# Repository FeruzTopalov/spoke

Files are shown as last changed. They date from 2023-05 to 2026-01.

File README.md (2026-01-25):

# **SPOKE*** - _Stay close!_ 
_*Like a spoke in a wheel_

<p align="center">
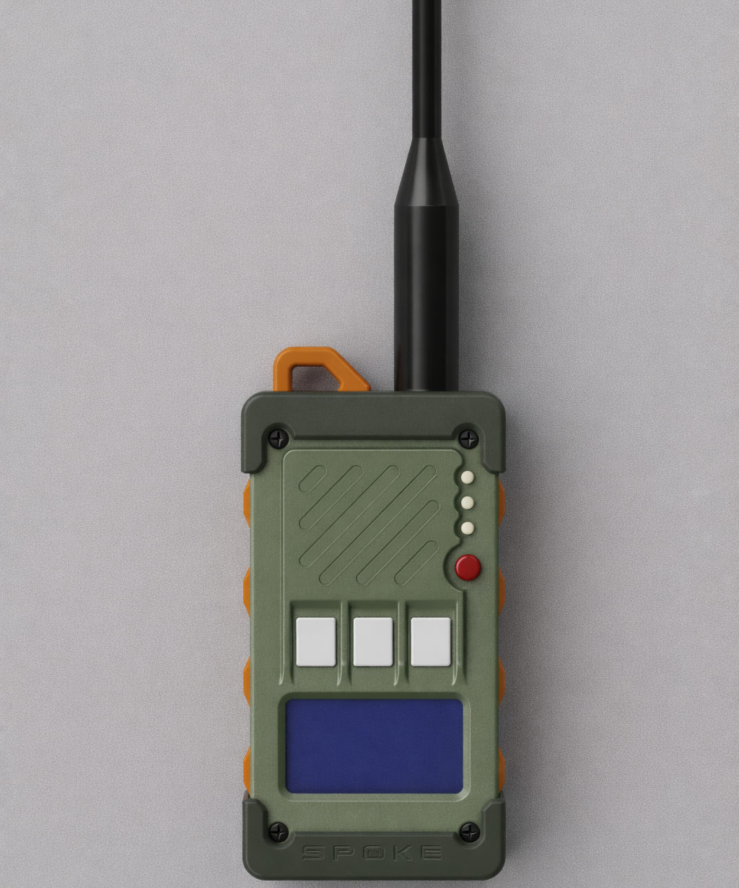
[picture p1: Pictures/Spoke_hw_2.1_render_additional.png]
Spoke Device Render
  
</p>

<p align="center">
🔓 Open-source<br>
🛠️ Open-hardware<br>
🛰️ GPS-based<br>
📡 LoRa-enabled<br>
🔋 Off-grid<br>
✨ Feature-rich<br>
🧭 Local Relative Navigation System<br>
<br>
or<br>
<br>
📍 just a LoRa GPS tracker for group 😉<br>
</p>

<p align="center">
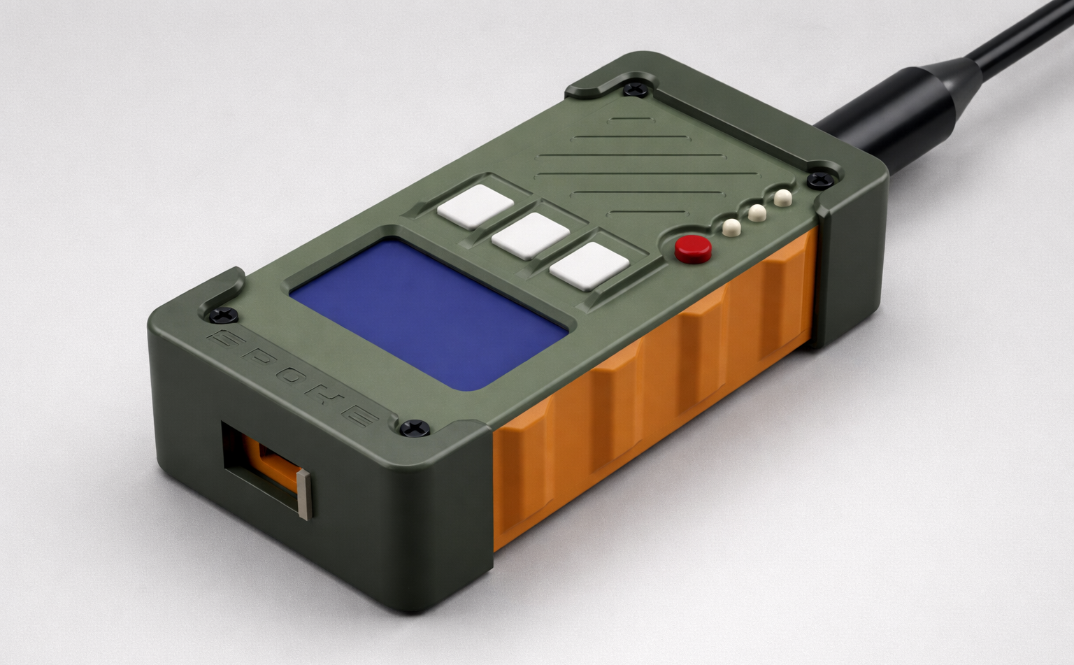
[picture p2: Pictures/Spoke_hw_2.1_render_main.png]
Spoke Device Render
  
</p>

---

## 📋 Table of Contents

- [About](#about)
- [Use Cases](#use-cases)
- [Key Features](#key-features)
- [Hardware](#hardware)
- [Technology & How It Works](#technology--how-it-works)
- [Navigation Algorithms](#navigation-algorithms)
- [Getting Started](#getting-started)
- [Configuration](#configuration)
- [Frequency Bands](#frequency-bands)
- [Community](#community)
- [Contributing](#contributing)
- [Support the Project](#support-the-project)

---

## About

**Spoke** is a GPS tracker for a group of up to 5 members. It enables **real-time positional data sharing** in a group, providing **Distance** and **Azimuth** information in a **radar-like interface** where a 360-degree azimuth circle shows your direction as a **spoke** and azimuth to target as a **notch**. 

<p align="center">
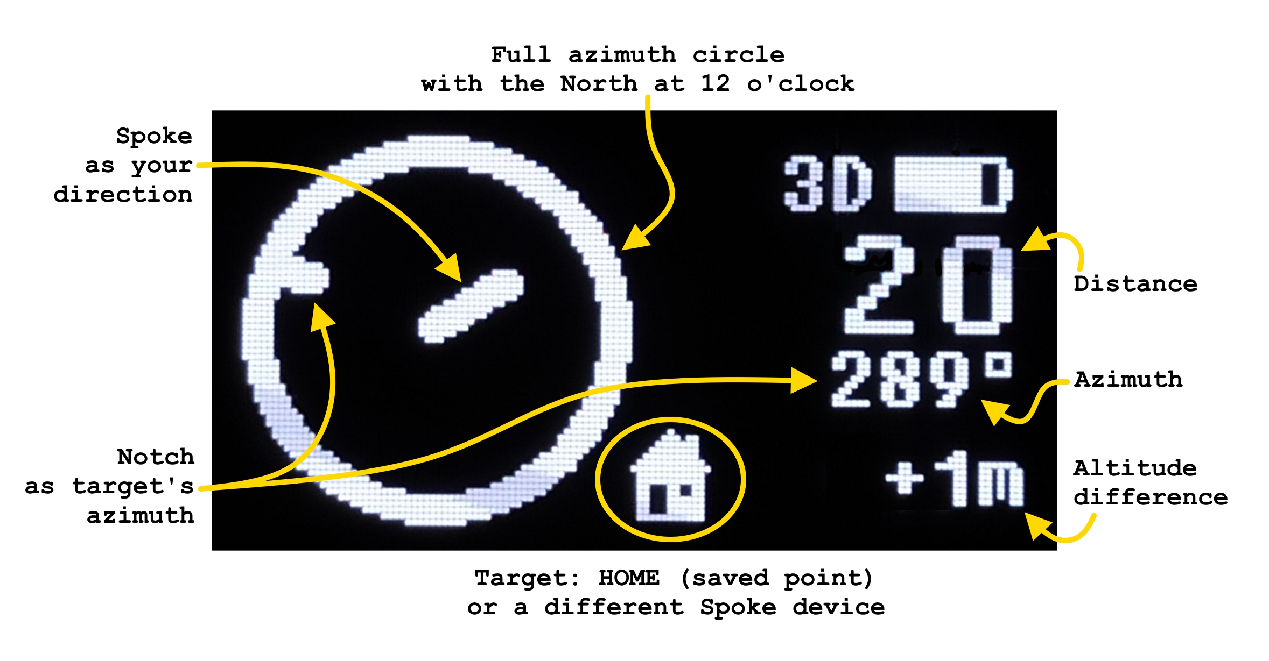
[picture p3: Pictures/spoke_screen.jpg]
User Interface Legend
  
</p>

Besides navigation function, Spoke has **extra safety features** like: 
- **Alarm distress signal** - with a dedicated red button to easily call group members for help
- **Timeout alert** - with configurable timeout in seconds
- **Radial geo-fence alert** - with configurable distance in meters

---

## Use Cases

Spoke's open-source nature and flexible hardware make it adaptable to numerous scenarios:

- 🥾 **Hiking & Trekking** - Keep your group together on trails
- 🧗 **Climbing & Mountaineering** - Track team members on challenging terrain
- ⛵ **Sailing & Boating** - Monitor vessel positions without AIS
- 🎿 **Skiing & Snowboarding** - Stay connected in backcountry areas
- 🏕️ **Camping & Outdoor Adventures** - Know where everyone is at camp
- 🐕 **Hunting with Dogs** - Track your hunting dogs' positions
- 📦 **Asset Tracking** - Monitor equipment or vehicles in remote locations
- 🚴 **Off-road Biking** - Keep your riding group coordinated
- 🔍 **Search & Rescue** - Coordinate team members during operations

---

## Key Features

### Navigation & Tracking
- **Real-time group tracking** for up to 5 devices with radar-like display
- **Absolute positioning** with GPS coordinates (latitude, longitude, altitude)
- **Relative positioning** with distance and azimuth to each group member
- **Memory points** to save locations and navigate to them later
- **Interactive eCompass** for quick orientation with ad-hoc calibration support
- **Magnetic and True North** display modes

### Communication
- **LoRa long-range radio** communication (up to several kilometers)
- **TDMA synchronization** using GPS PPS signal for collision-free transmission
- **Multi-band support:** 433 MHz or 868 MHz with 1% duty cycle compliance
- **License-free frequency channels** depending on the frequency band and country of operation
- **Configurable update intervals:** 10, 30, 60, or 120 seconds

### Safety Features
- **GeoFence alert** - notification when a member leaves defined circle around you
- **Timeout alert** - notification when connection to a member is lost for a defined time
- **Dedicated alarm button** for emergency signaling
- **Battery-low monitoring** and notification to other members

---

## Hardware

### PCB

Spoke is assembled on a simple, 2-layer, 1.6 mm thick PCB of 100 x 50 mm size. It uses well-known and popular electronic components that are easy to get. Some of them may be or already are obsolete, but are still available on the market, or even in your own stock! Spoke is not critical to values and nominals of components, so it can be easily adapted to your parts source. Some components are optional to install, which adds extra flexibility if you do not need particular functionality.

<p align="center">
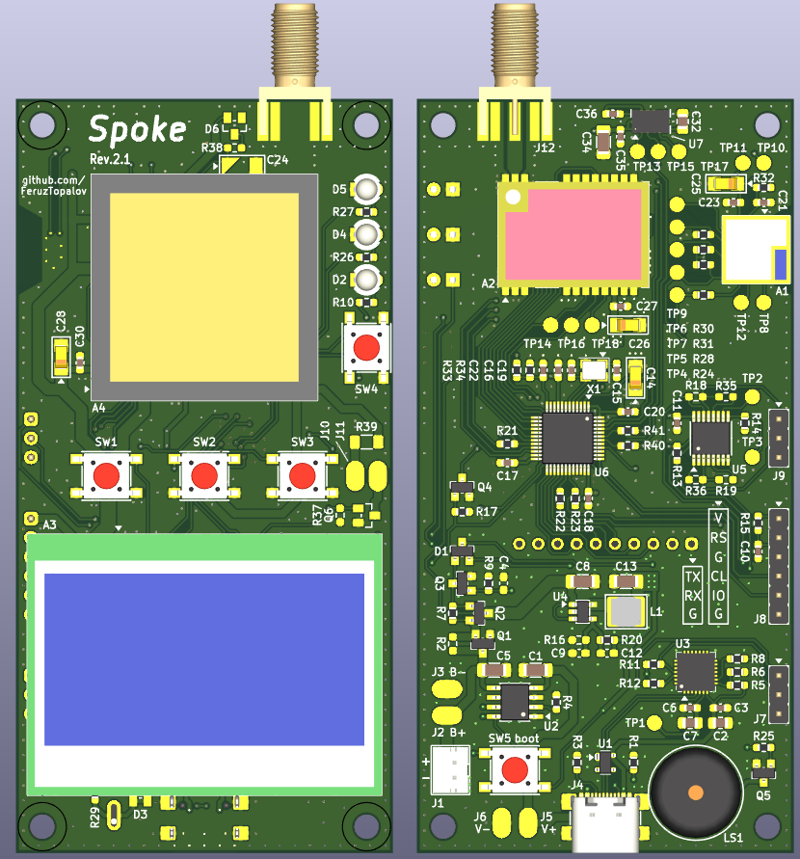
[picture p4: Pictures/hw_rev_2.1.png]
Spoke PCB
  
</p>

### Core Components

| Component | Specification | Purpose | Install option |
|---|---|---|---|
| **MCU** | STM32F103C8T6 (BluePill) | Main processing unit | Mandatory |
| **GPS Module** | QUESCAN models G10A-F30 or TU10-F <br> or any other with wires | Position and time synchronization | Mandatory |
| **Radio Module** | Semtech SX126x-based <br> E22-400M22S or E22-900M22S | LoRa communication | Mandatory |
| **Display** | 1.3" Monochrome LCD (ST7567 controller) | User interface | Mandatory |
| **eCompass** | LSM303DLHC | Orientation and motion sensing | Optional |
| **USB Interface** | Type-C with CP2102N-28 USB-UART converter | Programming and Nav data stream | Optional |
| **BLE Module** | E104-BT5005A BLE-UART bridge | Wireless Nav data stream | Optional |
| **Multiplexer** | 74HC4052PW | Switching Nav data stream between USB and BLE | Optional |
| **Power Regulator** | LM3671MF-3.3 DC/DC | Efficient power management |Mandatory |
| **Battery** | Li-ion/Li-Po 2200 mAh <br> 70 x 40 x 6 mm max  | Power source | Mandatory |
| **Charging IC** | TP4056 | Battery charging management | Mandatory |

---

## Technology & How It Works

### Software Architecture

Spoke firmware is written in **pure C** using CMSIS and runs on the STM32F103C8T6 ARM Cortex-M3 microcontroller. The firmware features:

- **Modular design** with compile-time configuration
- **Watchdog protection** for system stability
- **Peripheral clock gating** for power optimization
- **DMA-based data processing** for efficiency
- **Double-precision calculations** for navigation accuracy

### GPS Processing

- **Configurable baud rates** (9600, 38400, 57600 and 115200 baud)
- **NMEA-0183 stream parsing** with essential navigation sentences (RMC, GGA, GSA, GSV)
- **PPS (Pulse Per Second)** signal for precise time synchronization
- **Data extracted:** Time, date, position (lat/lon/alt), speed, course over ground, satellites info, PDOP quality

### Communication Protocol

<p align="center">
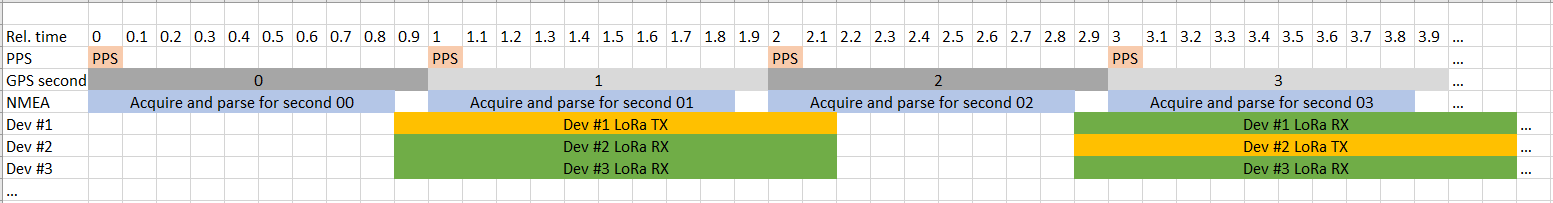
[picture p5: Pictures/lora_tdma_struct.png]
LoRa TDMA Structure
  
</p>

Spoke uses **Time Division Multiple Access (TDMA)** synchronized by GPS PPS signal:

1. **Time Reference:** GPS PPS signal triggers 900 ms processing window
2. **Data Collection:** NMEA data parsed and position prepared in the 900 ms window
3. **Time Slots:** Each device (numbered 1 to 5) transmits on dedicated even second of time: x0, x2, x4, x6, x8; where x = 0...5 depends on update interval setting
4. **Collision Avoidance:** TDMA ensures devices do not interfere with each other
5. **Update Intervals:** Configurable at 10, 30, 60, or 120 seconds

### LoRa Configuration

**Modulation Parameters:**
- **Spreading Factor:** SF12
- **Bandwidth:** 125 kHz
- **Coding Rate:** 4/8
- **Header:** Explicit mode, header disabled
- **CRC:** Enabled
- **Output Power:** -9 to +22 dBm (configurable)

**Packet Structure (13 bytes payload):**

| Preamble | Payload | CRC |
|---|---|-----|
| 8 symbols | 13 bytes | 2 bytes |

**Payload Format:**

| Flags | Device Number | Device ID | Latitude | Longitude | Altitude |
|---|---|---|---|---|---|
| 1 byte | 1 byte | 1 byte | 4 bytes | 4 bytes | 2 bytes |

**Time on Air:** 1.188 seconds per packet

### Nav data Output

Complete navigational data of all devices and saved points is available via:
- **Physical UART:** 115200 baud, accessible at console pin header
- **USB-UART:** Wired through CP2102N converter
- **BLE-UART:** Wireless via E104-BT5005A module
- **Format:** ISO 8601 timestamp + Base64-encoded Nav data

### Nav data Format

- **ISO 8601 Timestamp:** YYYY-MM-DDTHH:MM:SS+hh:mm where +/-hh:mm is timezone configured by user
  - 25 bytes size, fixed
- **Base64 Nav data:**
  - 9 navigation objects max (5 devices and 4 saved points)
  - 19 bytes each object
  - 171 bytes max Nav data size (raw, before Base64 encoding)
  - 228 bytes max Nav data size (final, after Base64 encoding)
  - **Format:** (little-endian)
    - Device Number - 1 byte, unsigned, range from 1 to 9
    - Device ID - 1 byte, ASCII char
    - Internal flags - 1 byte, bit field
      - bit 0 - is nav object your device
      - bit 1 - is nav object a memory point
      - bit 2 - is fence alarm triggered
      - bit 3 - is timeout alarm triggered
      - bit 4 - is nav object online (i.e. successful communication at last time slot)
    - External flags - 1 byte, bit field
      - bit 0 - is nav object in alarm
      - bit 1 - is nav object a beacon
      - bit 2 - is nav object in low battery state
      - bit 3 - is nav object's motion detected
      - bit 4 - is nav object's PDOP good
    - SNR value - 1 byte, signed (actual for devices only, but kept as 0 for saved points for unification)
    - Timeout  - 4 bytes, unsigned, seconds since last activity
    - Latitude - 4 bytes, float, decimal degree
    - Longitude - 4 bytes, float, decimal degree
    - Altitude - 2 bytes, signed, meters above mean sea level
- **Example:** "2025-03-02T10:45:00+02:00 AUERGAAAAAB+WUNCvHUSQGQA\r\n"
  - Max total size: 25 + 1 (space) + 228 + 2 (cr & lf) = 256 bytes

---

## Navigation Algorithms

Spoke implements high-precision navigation calculations using established mathematical formulas:

### Distance Calculation - Haversine Formula

The [Haversine formula](https://en.wikipedia.org/wiki/Haversine_formula) calculates the great-circle distance between two points on a sphere:

- **Advantages:** Numerically well-conditioned for small distances
- **Implementation:** Double-precision floating-point for accuracy
- **Accuracy:** <1% error for distances up to 300 km

### Bearing Calculation - Loxodrome (Rhumb Line)

The [Loxodrome formula](https://en.wikipedia.org/wiki/Rhumb_line) determines constant bearing to destination:

- **Advantages:** Provides constant compass bearing (easier to follow)
- **Implementation:** Accounts for Mercator projection
- **Practical Use:** More useful than great-circle route for navigation
- **Accuracy:** Very close in distance to Great Circle Route at short distances

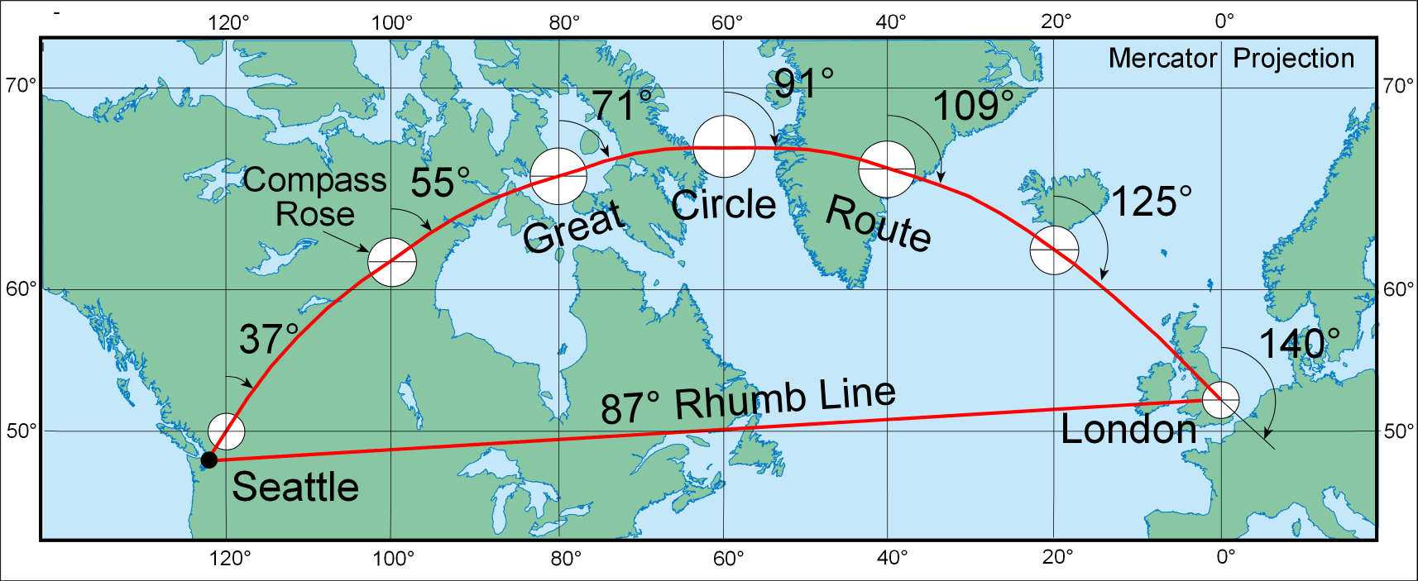
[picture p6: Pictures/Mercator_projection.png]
Mercator Projection


<p align="center">
  <i>(Mercator projection - courtesy of <a href="https://www.esri.com/arcgis-blog/products/product/mapping/mercators-500th-birthday/">ESRI</a>)</i>
</p>

---

## Getting Started

### Prerequisites

**Hardware Requirements:**
- Spoke devices (at least two to form a group)
- USB Type-C cable for UART bootloader programming
- ST-Link for SWD programming
- Lithium-ion battery
- LoRa antenna (433 MHz or 868 MHz, depending on configuration)

**Software Requirements:**
- STM32CubeIDE for compilation
- STM32CubeProgrammer for flashing

### HW & FW Versions

To access a specific version of Spoke HW or FW refer to Git Tags. See the latest versions in [CHANGELOG](CHANGELOG.md)

### Building Firmware

See [Configuration, Compilation and Programming Instruction](CubeIDE/README.md)

---

## Configuration

### Compile-Time Configuration (config.h)

The firmware uses compile-time defines for hardware-specific settings:

```c
/* PART A - user-defined */

/* Step 1 - Select Spoke HW Revision */
//#define SPOKE_HW_REV_1_x	/* Spoke HW 1.x */
//#define SPOKE_HW_REV_2_0	/* Spoke HW 2.0 */
#define SPOKE_HW_REV_2_1	/* Spoke HW 2.1 */

/* Step 2 - Select GPS Baud Speed */
//#define GPS_BAUD_9600
#define GPS_BAUD_38400
//#define GPS_BAUD_57600
//#define GPS_BAUD_115200	/* Operation at 115200 is not guaranteed due to limited buffer size */

/* Step 3 - Select Frequency Band */
//#define FREQ_BAND_433		/* Define for E22-400M22S module (SX1268) if it is populated in any HW revision */
#define FREQ_BAND_868		/* Define for E22-900M22S module (SX1262) if it is populated in any HW revision */
```

### Runtime Configuration (Settings Menu)

Access settings via button interface:
- **Device number** (1 - 5)
- **Group size** (2 - 5)
- **Device ID** (A - Z)
- **Update interval** (10, 30, 60, 120 sec)
- **Frequency channel** (1 - 8 for 433 band, 1 - 21 for 868 band)
- **TX power** (-9, 0, +10, +14, +22 dBm)
- **Timeout alarm** (0 - 3600 sec, 10 sec increment) 
- **Fence** (0 - 5000 m, 10 m increment)
- **Timezone** (-12 - +14 h, 15 min increment)

---

## Frequency Bands

⚠️ **Important:** Ensure you comply with your local radio frequency regulations before operating Spoke! Configure update interval, frequency channel and TX output power according to them!

### 433 MHz Band

| Channel | Frequency |
|---|---|
| CH 1 | 433.175 |
| CH 2 | 433.375 |
| CH 3 | 433.575 |
| CH 4 | 433.775 |
| CH 5 | 433.975 |
| CH 6 | 434.175 |
| CH 7 | 434.375 |
| CH 8 | 434.575 |

### 868 MHz Band

| Channel | Frequency |
|---|---|
| CH 1  | 865.100 |
| CH 2  | 865.300 |
| CH 3  | 865.500 |
| CH 4  | 865.700 |
| CH 5  | 865.900 |
| CH 6  | 866.100 |
| CH 7  | 866.300 |
| CH 8  | 866.500 |
| CH 9  | 866.700 |
| CH 10 | 866.900 |
| CH 11 | 867.100 |
| CH 12 | 867.300 |
| CH 13 | 867.500 |
| CH 14 | 867.700 |
| CH 15 | 867.900 |
| CH 16 | 868.100 |
| CH 17 | 868.300 | 
| CH 18 | 868.500 |
| CH 19 | 868.700 |
| CH 20 | 868.900 |
| CH 21 | 869.100 |

---

## Community

- **Telegram Group: [RU, EN]** [https://t.me/lrns_eleph](https://t.me/lrns_eleph)
  - Share experiences and demonstrations
  - Get help with building and troubleshooting
  - Discuss new features and improvements
  - Connect with other Spoke users

---

## Contributing

We welcome contributions from the community! Here is how you can help:

1. **Test and Report Issues**
   - Build the device and test in real-world conditions
   - Report bugs via GitHub Issues
   - Share your use case and feedback

2. **Code Contributions**
   - Fork the repository
   - Create a feature branch
   - Submit pull requests with improvements
   - Follow existing code style and conventions

3. **Hardware Improvements**
   - Suggest PCB layout optimizations
   - Test alternative components
   - Share manufacturing tips

4. **Documentation**
   - Improve README and guides
   - Add translations
   - Create tutorials and examples

5. **Community Support**
   - Help other users in Telegram group
   - Share your builds and experiences
   - Write blog posts or make videos about Spoke

---

## Support the Project

The best way to support Spoke is through **active participation**:
- Build and test the device
- Report issues and contribute fixes
- Join the community and help others
- Share your experience and use cases

### Financial Support
If you'd like to support development financially:
- **Boosty:** [https://boosty.to/feruztopalov/donate](https://boosty.to/feruztopalov/donate)
  - One-time donations
  - Subscriptions with exclusive bonuses

---

<p align="center">
  Made with ❤️ by the Spoke community
</p>

<p align="center">
  <strong>Stay Connected. Stay Safe. Stay Close.</strong>
</p>

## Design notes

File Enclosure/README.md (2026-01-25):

# Enclosures for Spoke

_newest to oldest_

- Endeavour
  - For Spoke HW Rev. 2.1
  - Brick design, meticulous and catchy
  - 604070 battery
  - Only for 1.6 mm PCB thickness
- Pioneer
  - For Spoke HW Rev. 1.2
  - Ergonomic design based on Voyager enclosure
  - 18650 battery with embedded holder
  - Available for 1.0 and 1.6 mm PCB thicknesses
- Voyager
  - For Spoke HW Rev. 1.0
  - Timber design
  - 18650 battery
  - Available for 1.0 and 1.6 mm PCB thicknesses
- Enterprise
  - For Spoke HW Rev. 1.0
  - Flattish design
  - 18650 battery
  - Available for 1.0 and 1.6 mm PCB thicknesses

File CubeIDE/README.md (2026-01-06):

# Source code

- Written in C, using CMSIS and direct registers access  
- IDE: STM32CubeIDE Version: 1.17.0 

# HEX Compilation

1. Open project in STM32CubeIDE
1. Open and edit "config.h"
1. Select via defines **Spoke HW revision** you have, **baud speed of the GPS module** you use, and **frequency band of the LoRa module** you populated
1. Click Build-All (Ctrl+B) for any configuration, either "Debug" or "Release" - they are configured to be equivalent
1. Find "Spoke.hex" in "Debug" or "Release" folder depending on the configuration you compiled for

# Programming

## Using SWD (ST-Link) - guaranteed

1. Run STM32CubeIDE
1. Select ST-LINK programming mode
1. Connect your programmer to SWD interface lines available on all Spoke HW versions
1. Connect at least SWDCLK (marked CL), SWDIO (marked IO) and GND (marked G)
1. With battery connected to Spoke, push down the power button and **hold it down until programming is done**
1. Erase all and flash the HEX file
1. Once flashing is done you should hear sartup beep and LCD showing loading screen
1. Release power button and disconnect from the programmer

## Using UART (STM32 bootloader) - only Spoke HW Rev.2.x

1. Run STM32CubeIDE
1. Select UART programming mode
1. Depending on Spoke PCB variant you either use external USB-UART module connected to console pins or Spoke built-in USB-UART converter if populated
1. In first case connect your external UART module to UART lines (Spoke TX line is marked as TX; Spoke RX line is marked as RX; do not forget to cross lines towards external UART module) or 
1. Connect external UART module to USB or connect Spoke USB-C cable to computer 
1. Click connect in STM32CubeIDE to appropriate COM port (you may need driver for Spoke USB-UART; install "CP210x USB to UART Bridge VCP Drivers" from Silabs website) 
1. When successfully connected to the COM port, enter STM32 bootloader mode by holding down power button when boot button is pressed. **Keep holding power button down untill programming is done**
1. There is alternative way to enter STM32 bootloader if Spoke FW is already flashed, see next section
1. STM32CubeIDE should report on successfult bootloader connect with bootloader version and MCU type. You may release boot button then
1. Erase all and flash the HEX file
1. Release power button and disconnect from the programmer
1. Power up Spoke to make sure it is working

## Using UART (STM32 bootloader) - alternative way any Spoke HW

1. There is a way to use STM32 bootloader in any Spoke HW revision if initial programming was done and Spoke FW is flashed
1. Holding OK button upon power up switches to STM32 bootloader through Spoke FW, so you do not need boot button as required in the above section which is only present in Spoke HW Rev.2.x
1. This makes it possible to use STM32 bootloader even in Spoke HW 1.x for FW updates

# Default settings

- Any FW update is recommended to be done with full MCU flash erase to rewrite settings area in memory
- In some cases settings area is not overwrittent (for example when you are flashing directly from CubeIDE)
- When any Spoke FW is already flashed you can reset setting to default by holding ESC button upon power up. You will be prompted to reset them interactive way

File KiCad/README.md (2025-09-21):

# Hardware design

Designed in KiCad version 9.0.4  
PCB stack-up: 100 x 50 mm, typical FR-4, 2 layers, 1 o.z., 1.6 mm thickness, 0.2 mm track/clearance, 0.3/0.6 mm via

See PRODUCTION folder for:
- "3D" - STEP model of PCB
- "BOM" - Bill of Materials
- "PCB" - Gerber files
- "SCH" - Circuit schematic

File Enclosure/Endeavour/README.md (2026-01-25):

# "Endeavour" enclosure

Author: Andrew   
Designed and tested for Spoke HW Rev. 2.1  
Pre-install 4x M2 inserts and fix with 4x M2*15 or *20 screws  
Print 2x "pin.stl" and 3x "button.stl"

<p align="center">
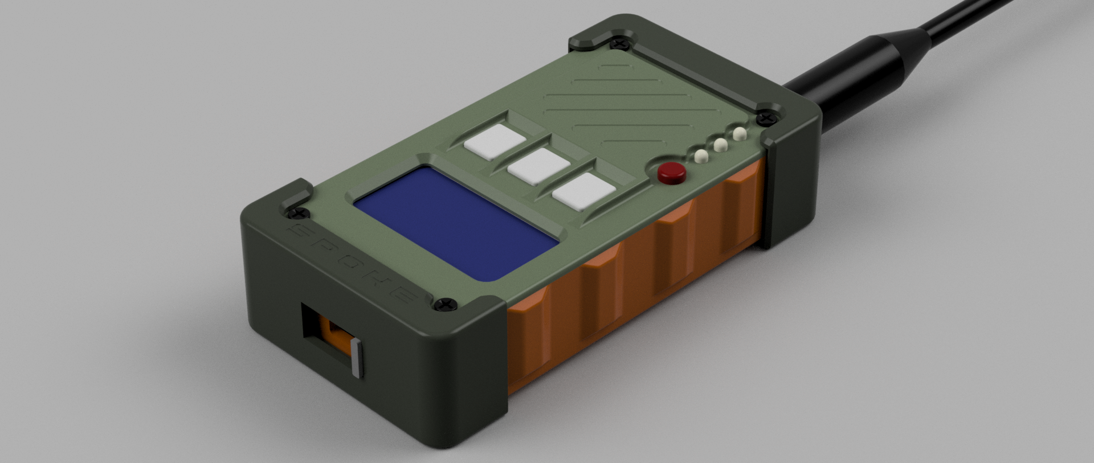
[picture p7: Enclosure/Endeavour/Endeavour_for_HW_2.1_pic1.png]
  
</p>

<p align="center">
  
</p>

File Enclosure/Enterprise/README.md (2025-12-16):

# "Enterprise" enclosure

Author: Andrew I.   
Designed and tested for Spoke HW Rev. 1.0  
Fix with 5x M3*20 DIN 7985

<p align="center">
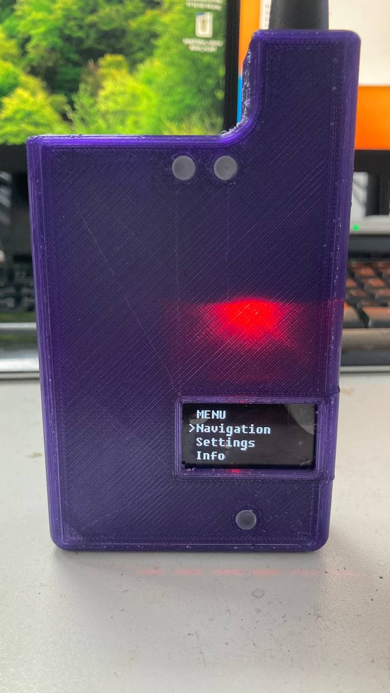
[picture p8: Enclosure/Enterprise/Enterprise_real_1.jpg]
  
</p>

<p align="center">
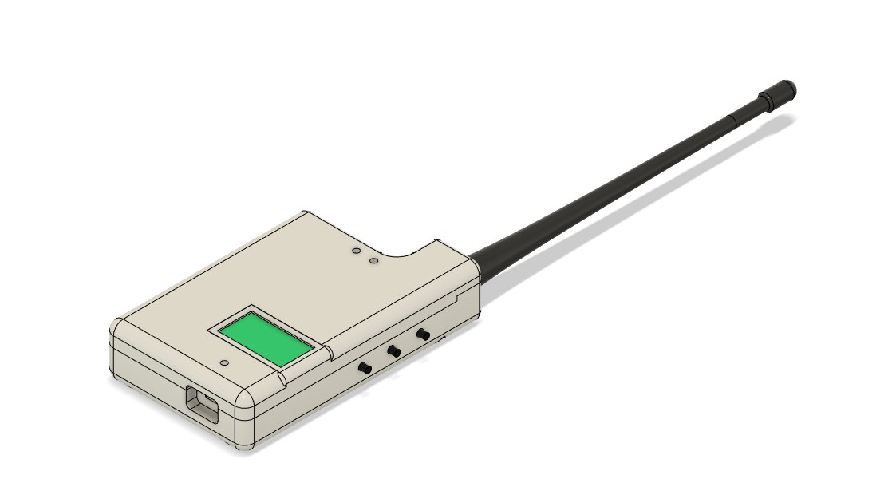
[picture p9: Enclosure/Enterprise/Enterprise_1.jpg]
  
</p>

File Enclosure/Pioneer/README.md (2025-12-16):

# "Pioneer" enclosure

Author: Feruz   
Designed and tested for Spoke HW Rev. 1.2  
Fix with 4x M3*20 DIN 7985

<p align="center">
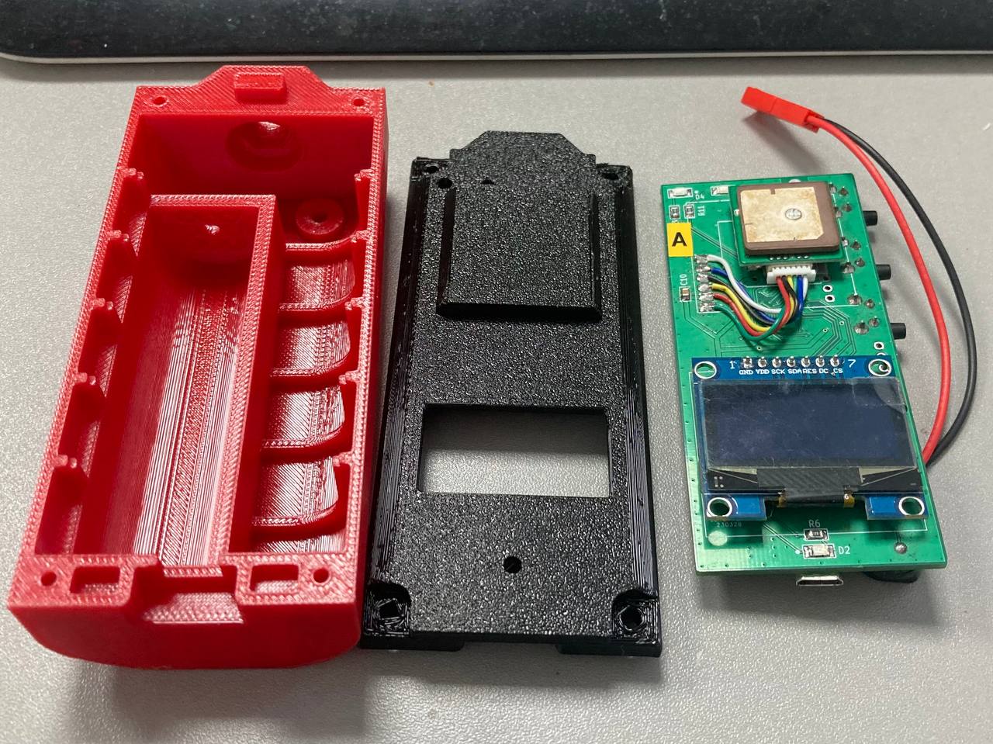
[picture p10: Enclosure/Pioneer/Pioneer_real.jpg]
  
</p>

<p align="center">
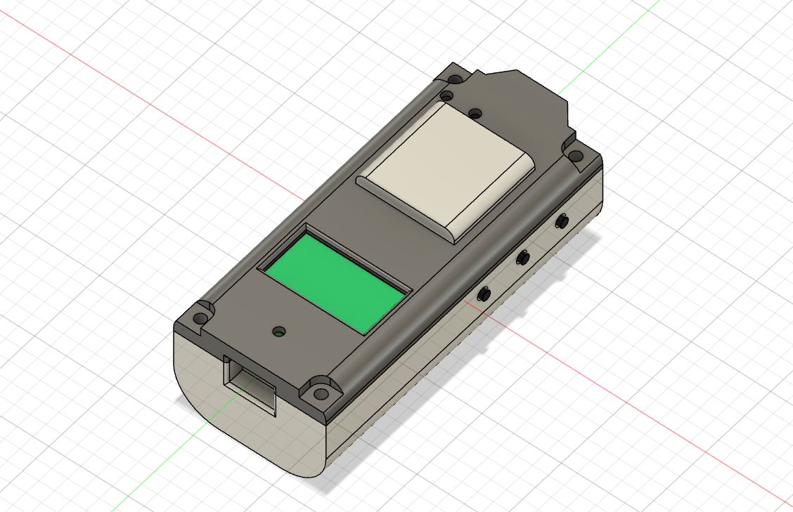
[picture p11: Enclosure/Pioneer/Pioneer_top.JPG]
  
</p>

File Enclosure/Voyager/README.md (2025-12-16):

# "Voyager" enclosure

Author: Andrew I.   
Designed and tested for Spoke HW Rev. 1.0  
Fix with 4x M3*20 DIN 7985

<p align="center">
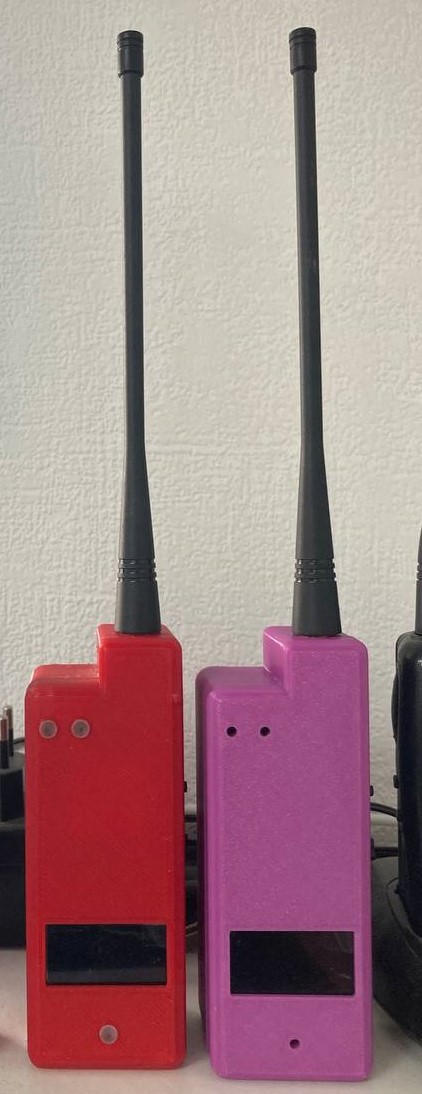
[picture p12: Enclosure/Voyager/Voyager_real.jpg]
  
</p>

<p align="center">
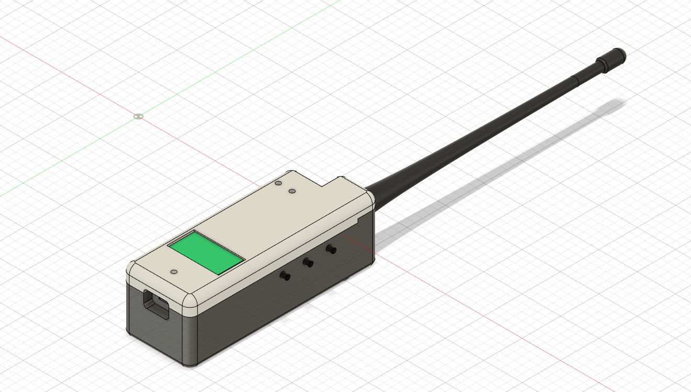
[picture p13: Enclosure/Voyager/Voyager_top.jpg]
  
</p>

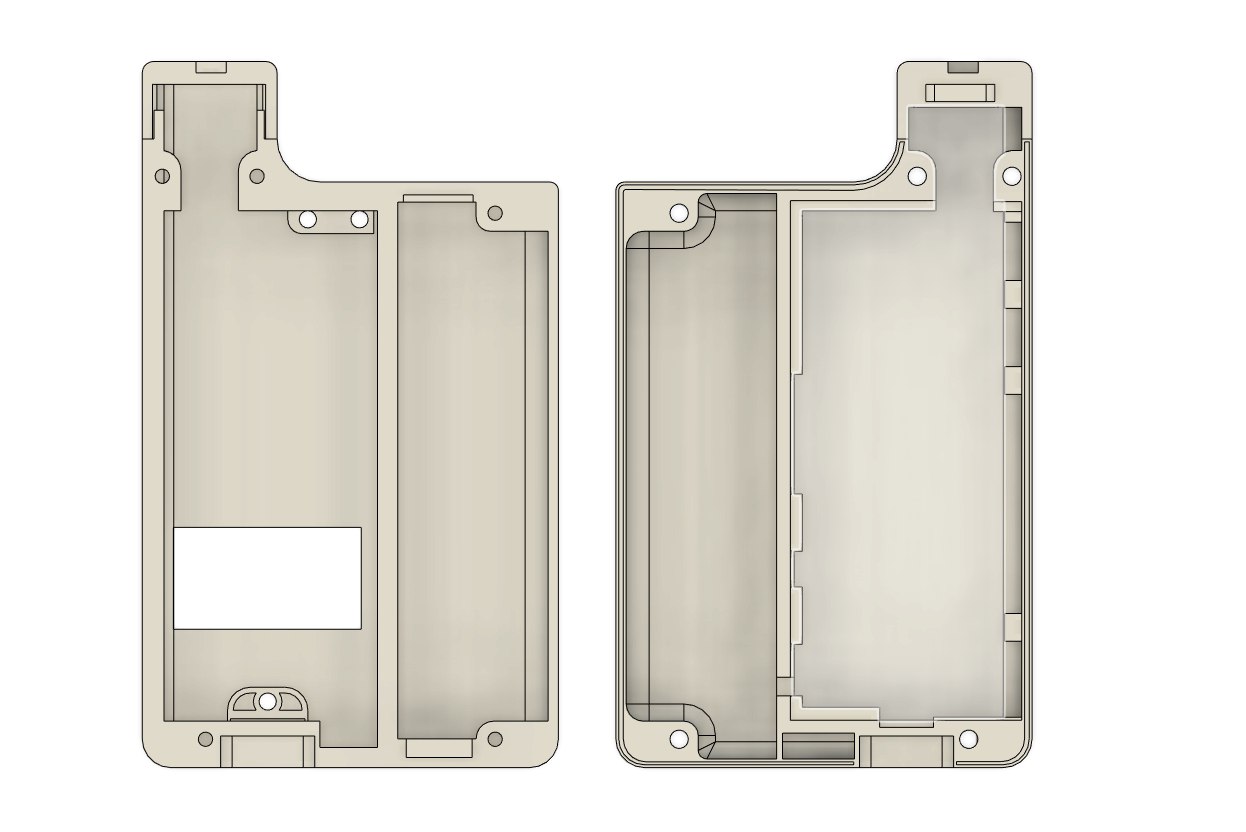
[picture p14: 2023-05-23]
Enclosure/Enterprise/Enterprise_3.jpg

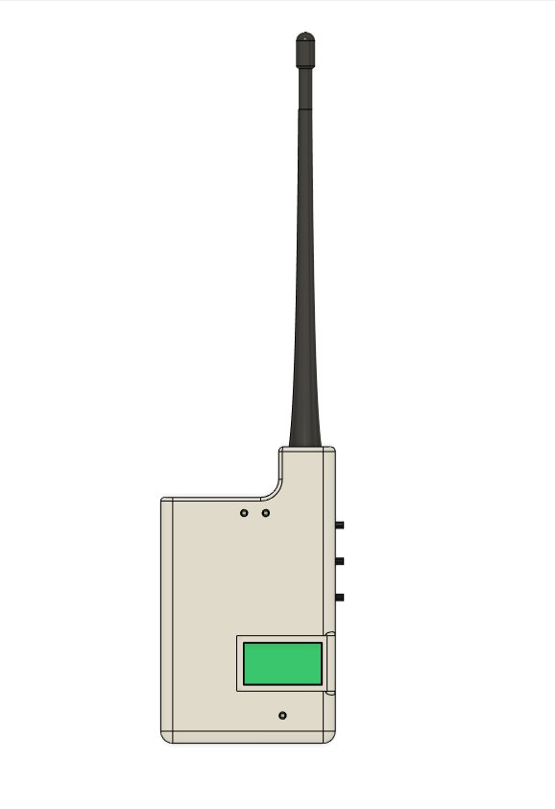
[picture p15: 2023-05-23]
Enclosure/Enterprise/Enterprise_7.jpg

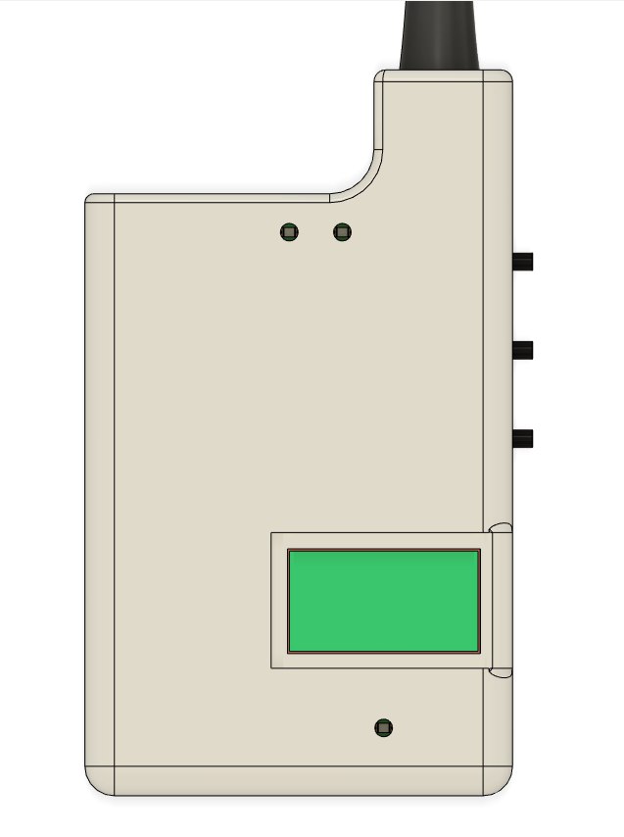
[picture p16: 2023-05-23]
Enclosure/Enterprise/Enterprise_6.jpg

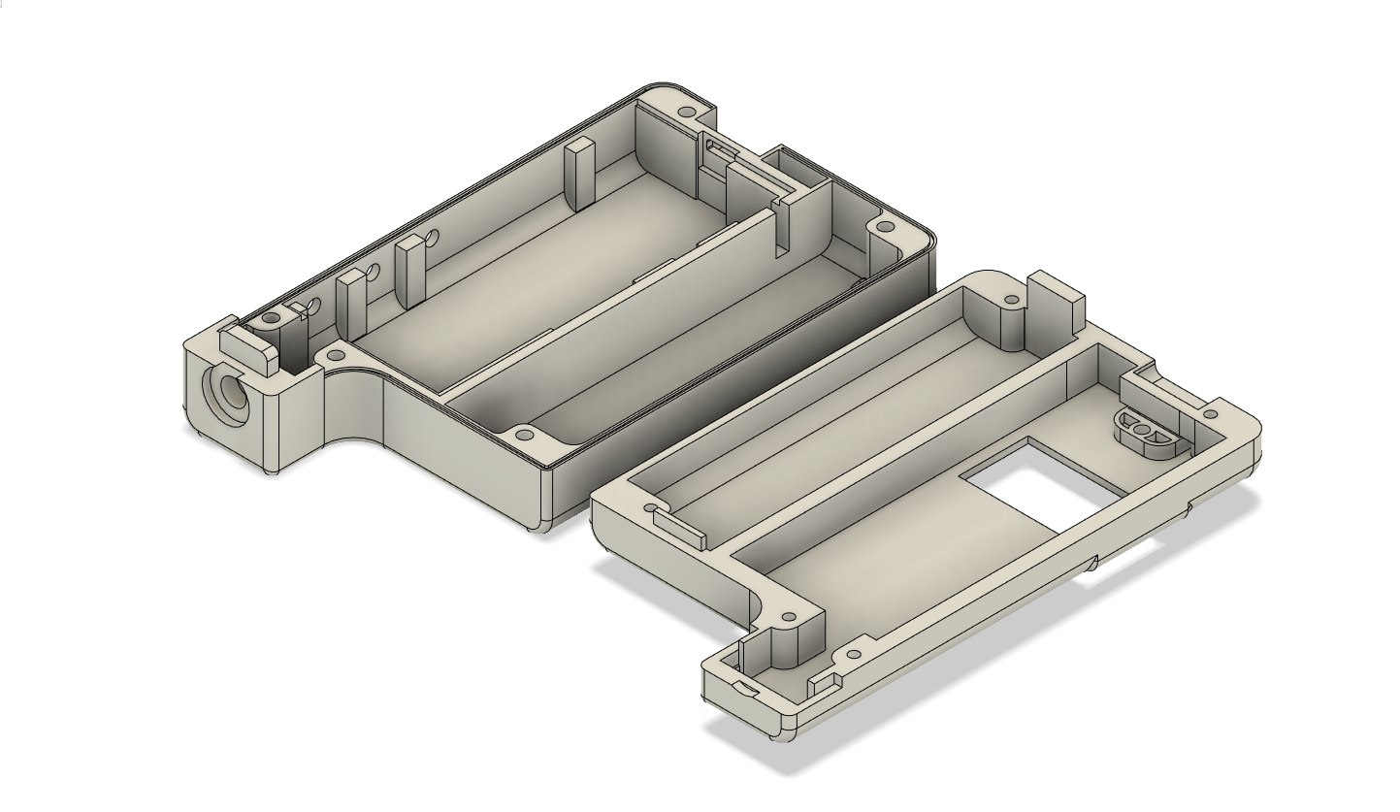
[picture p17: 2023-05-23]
Enclosure/Enterprise/Enterprise_5.jpg

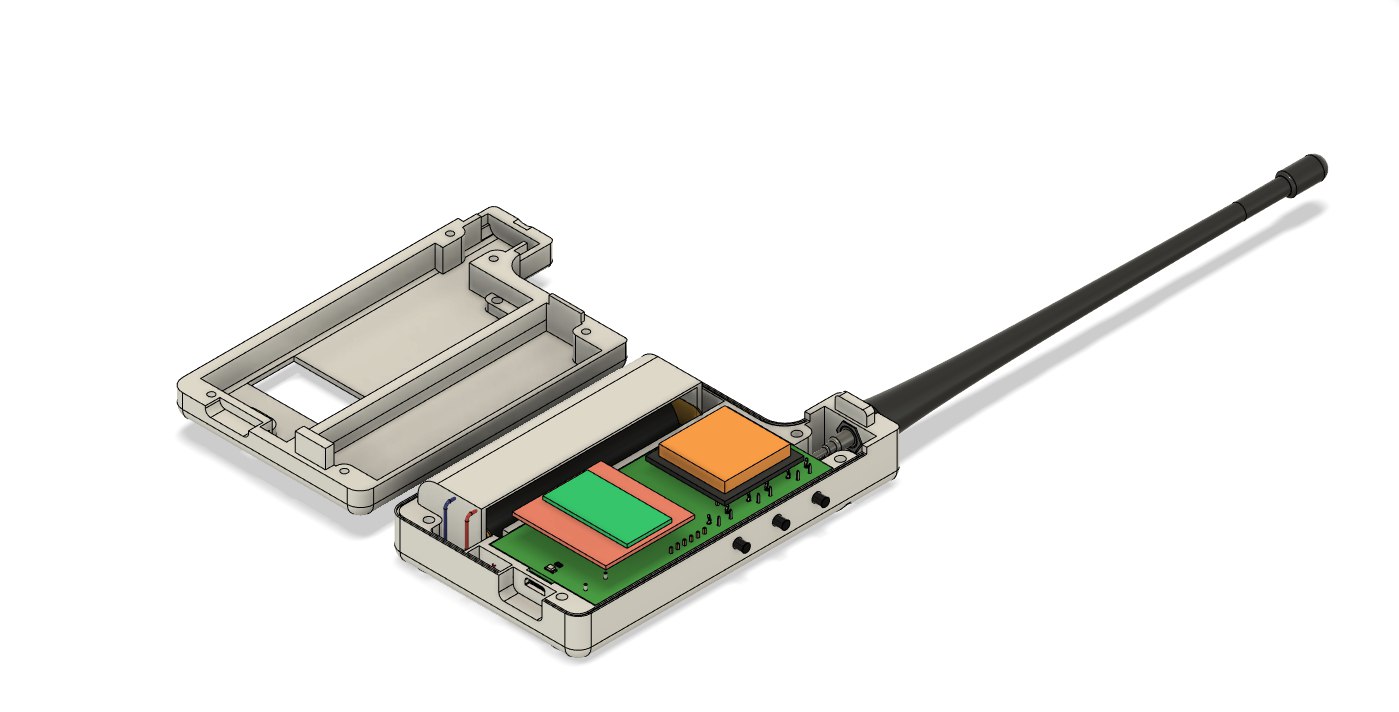
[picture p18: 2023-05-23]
Enclosure/Enterprise/Enterprise_2.jpg

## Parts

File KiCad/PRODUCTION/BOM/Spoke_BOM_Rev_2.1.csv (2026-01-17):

# | Reference | Value | Qty | Footprint
1 | A1 | E104-BT5005A | 1 | Spoke:E104-BT5005A
2 | A2 | E22-400M22S | 1 | Spoke:E22
3 | A3 | GM12864-01A | 1 | Spoke:GM12864-01A
4 | A4 | G10A-F30 | 1 | Spoke:G10A-F30
5 | C36 | 220nF | 1 | Spoke:C0603
6 | C1,C5,C8,C13,C34 | 10uF | 5 | Spoke:C1206
7 | C14,C25,C26,C28 | 47uF | 4 | Spoke:C_tantA
8 | C15,C19 | 12pF | 2 | Spoke:C0603
9 | C2,C7,C32 | 4.7uF | 3 | Spoke:C0805
10 | C3,C6,C10,C11,C16,C17,C18,C20,C21,C22,C23,C27,C30,C33,C35 | 100nF | 15 | Spoke:C0603
11 | D1 | BAT54C | 1 | Spoke:SOT-23
12 | D5 | Green | 1 | Spoke:LED_3mm
13 | D2,D4 | Red | 2 | Spoke:LED_3mm
14 | J1 | B2B-PH-K-S | 1 | Spoke:B2B-PH-2.0
15 | J4 | GCT USB4105/USB4110 | 1 | Spoke:USB_C_16p_GCT4105
16 | J8 | PLS-1x6 | 1 | Spoke:Header_1x6
17 | J12 | Amphenol 132289 | 1 | Spoke:SMA
18 | J7,J9 | PLS-1x3 | 2 | Spoke:Header_1x3
19 | L1 | 2.2uH | 1 | Spoke:L1616
20 | LS1 | Buzzer-Passive | 1 | Spoke:Buzzer
21 | Q1,Q2 | AO3407A | 2 | Spoke:SOT-23
22 | Q3,Q4,Q5 | AO3400 | 3 | Spoke:SOT-23
23 | R5 | 22.1kR | 1 | Spoke:R0603
24 | R6 | 47.5kR | 1 | Spoke:R0603
25 | R20 | 0R | 1 | Spoke:R0603
26 | R25 | 300R | 1 | Spoke:R0603
27 | R1,R3 | 5.1kR | 2 | Spoke:R0603
28 | R4,R21,R40,R41 | 3.9kR | 4 | Spoke:R0603
29 | R7,R9,R11,R13,R14,R15,R17,R23,R28,R30,R32,R33,R34 | 100kR | 13 | Spoke:R0603
30 | R8,R10,R12,R22,R24,R26,R27,R29,R31 | 1kR | 9 | Spoke:R0603
31 | SW1,SW2,SW3,SW4,SW5 | ~ | 5 | Spoke:Button_6x6
32 | U1 | SP0503BAHTG | 1 | Spoke:SOT-143
33 | U2 | TP4056 | 1 | Spoke:SOIC-8-EP
34 | U3 | CP2102N-A02-GQFN28 | 1 | Spoke:QFN-28
35 | U4 | LM3671MF-3.3 | 1 | Spoke:SOT-23-5
36 | U5 | 74HC4052PW | 1 | Spoke:TSSOP-16
37 | U6 | STM32F103C8T6 | 1 | Spoke:LQFP-48
38 | U7 | LSM303DLHC | 1 | Spoke:LGA-14
39 | X1 | 8MHz | 1 | Spoke:Xtal_3225

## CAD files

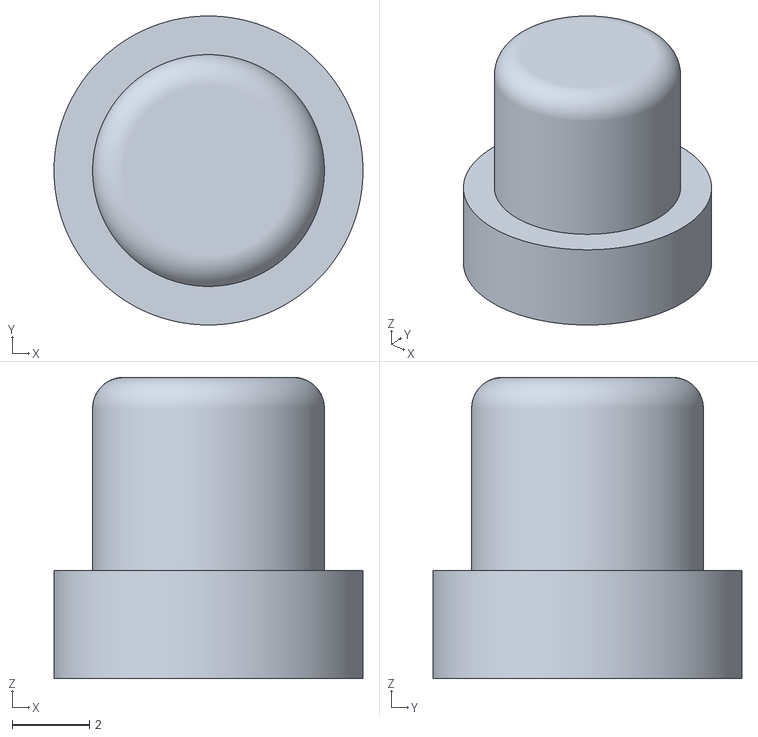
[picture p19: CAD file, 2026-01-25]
Enclosure/Endeavour/1.6mm PCB/alarm.stl
8.00 x 8.00 x 7.80

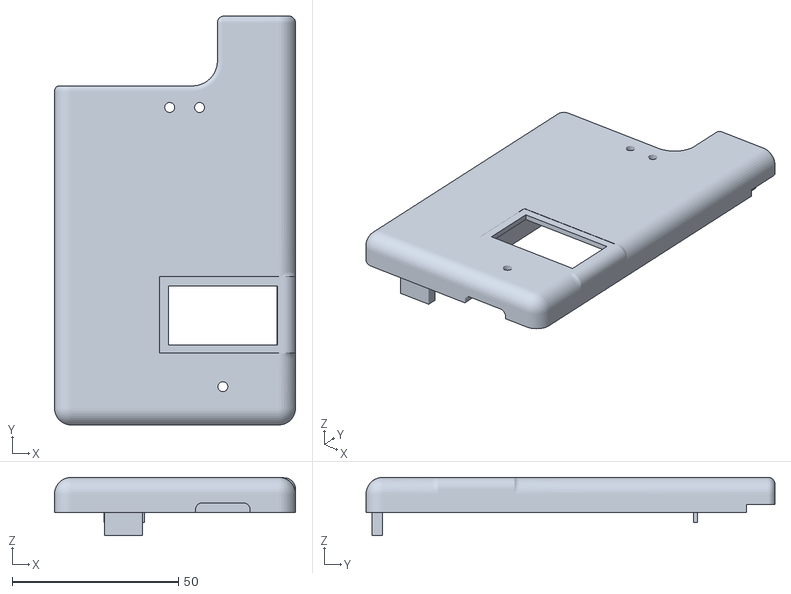
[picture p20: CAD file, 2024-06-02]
Enclosure/Enterprise/1.6mm PCB/Spoke_Enterprise_Top_1.6mm.stl
72.5 x 123.0 x 17.5

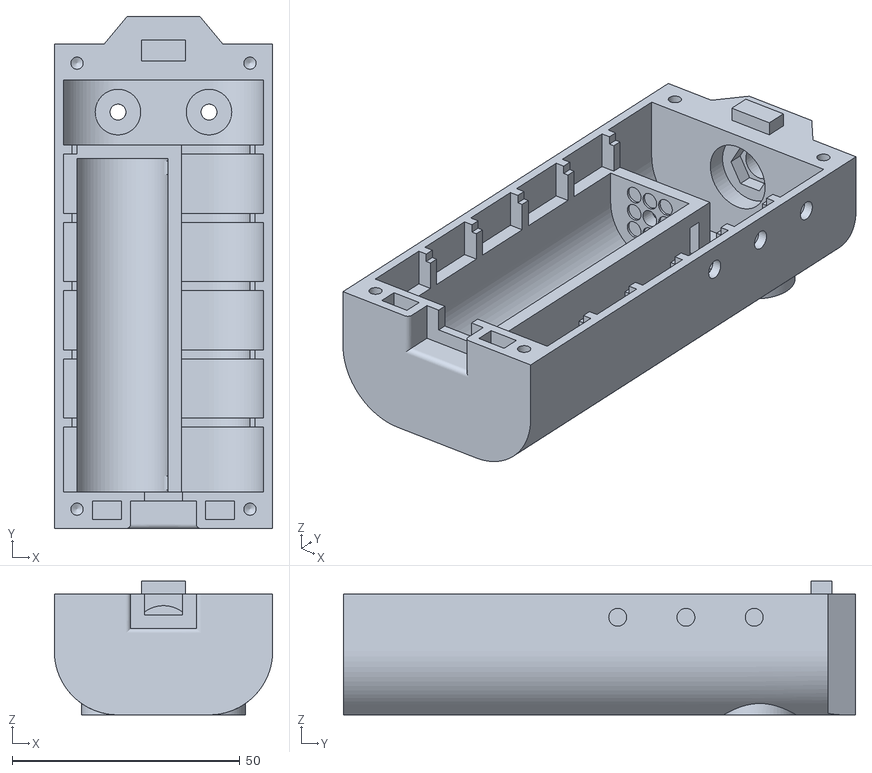
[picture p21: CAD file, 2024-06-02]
Enclosure/Pioneer/1.6mm PCB/Spoke_Pioneer_Bot_1.6mm.stl
48.0 x 112.5 x 29.4

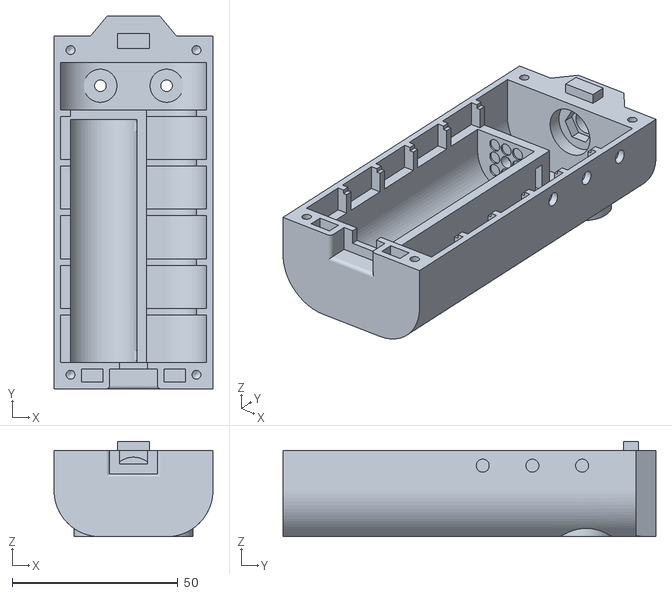
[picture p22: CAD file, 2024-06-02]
Enclosure/Pioneer/1mm PCB/Spoke_Pioneer_Bot_1.0mm.stl
48.0 x 112.5 x 28.8

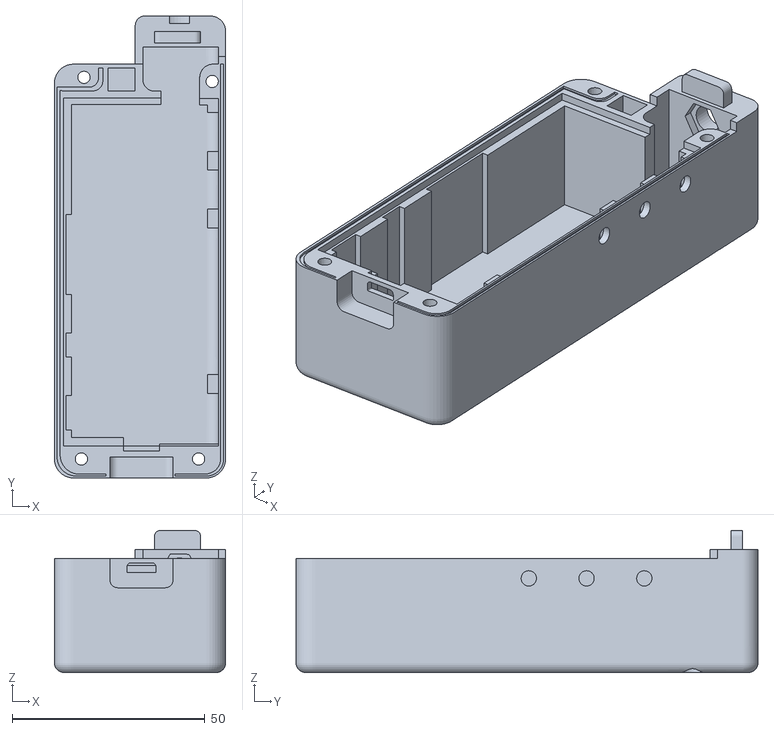
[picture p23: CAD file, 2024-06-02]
Enclosure/Voyager/1.6mm PCB/Spoke_Voyager_Bot_1.6mm.stl
44.5 x 120.0 x 36.9

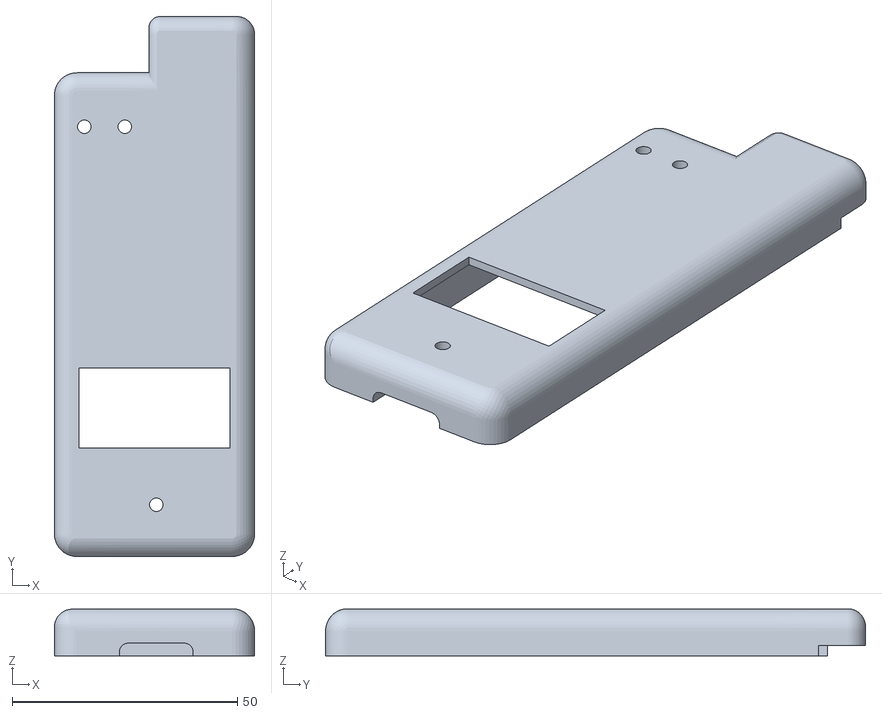
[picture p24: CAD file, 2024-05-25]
Enclosure/Voyager/1mm PCB/Spoke_Voyager_Top_1.0mm.stl
44.5 x 120.0 x 10.4

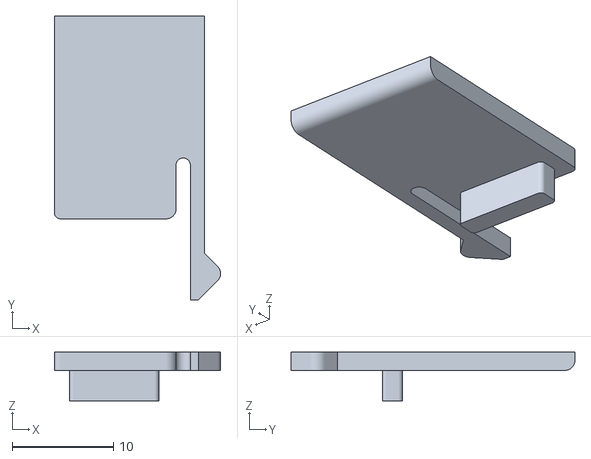
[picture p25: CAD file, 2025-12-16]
Enclosure/Endeavour/1.6mm PCB/stvorka.stl
16.4 x 28.0 x 4.80

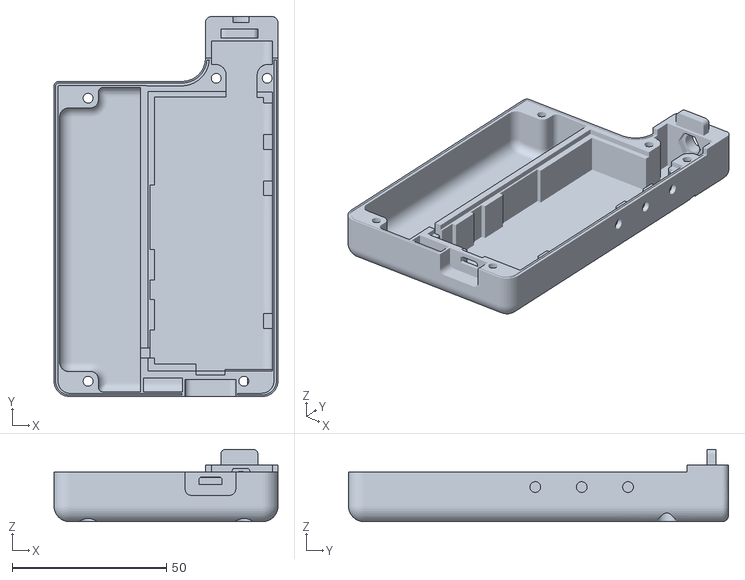
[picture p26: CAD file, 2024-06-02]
Enclosure/Enterprise/1.6mm PCB/Spoke_Enterprise_Bot_1.6mm.stl
72.5 x 123.0 x 23.4

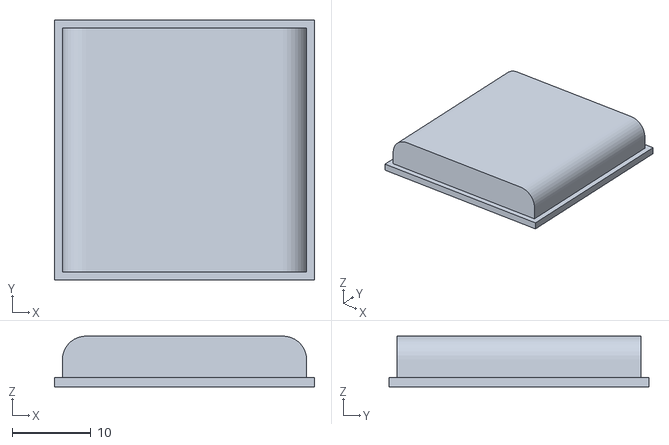
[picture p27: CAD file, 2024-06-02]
Enclosure/Pioneer/1.6mm PCB/Spoke_Pioneer_Cap_1.6mm.stl
33.0 x 33.0 x 6.45

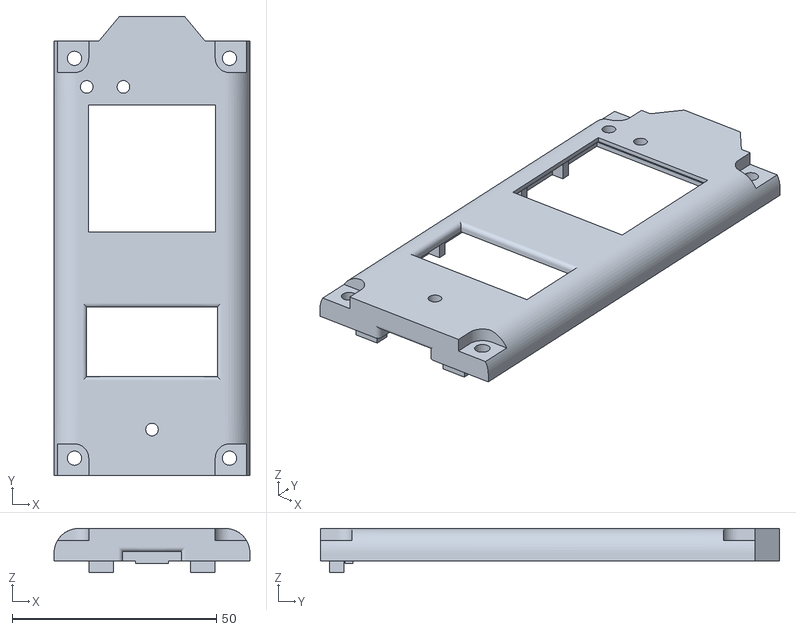
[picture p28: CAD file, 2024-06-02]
Enclosure/Pioneer/1mm PCB/Spoke_Pioneer_Top_1.0mm.stl
48.0 x 112.5 x 10.8

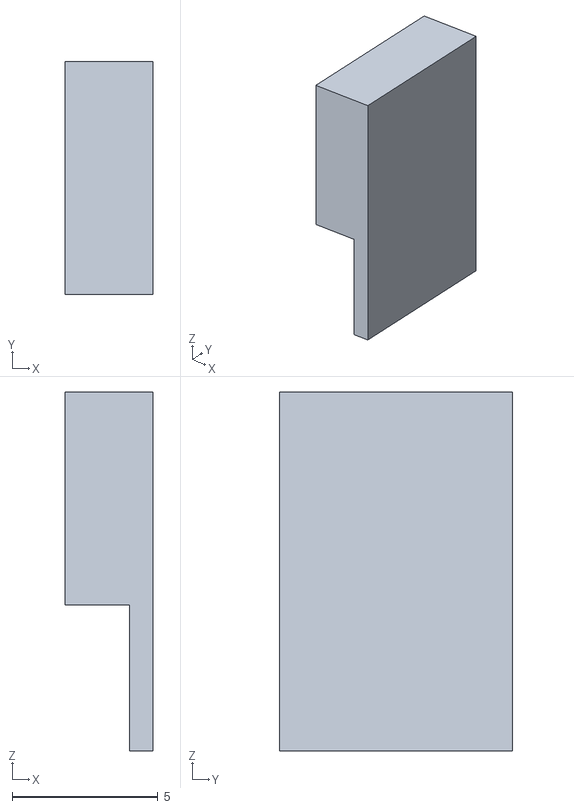
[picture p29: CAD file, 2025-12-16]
Enclosure/Endeavour/1.6mm PCB/pin.stl
3.00 x 8.00 x 12.3

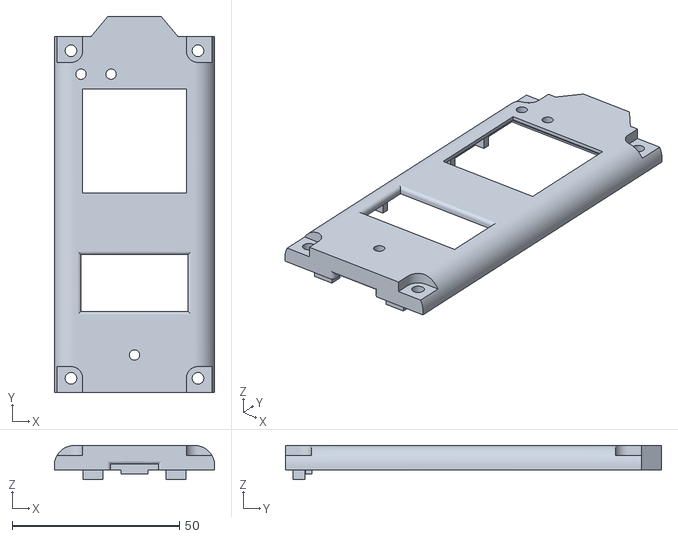
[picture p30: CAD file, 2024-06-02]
Enclosure/Pioneer/1.6mm PCB/Spoke_Pioneer_Top_1.6mm.stl
48.0 x 112.5 x 10.2

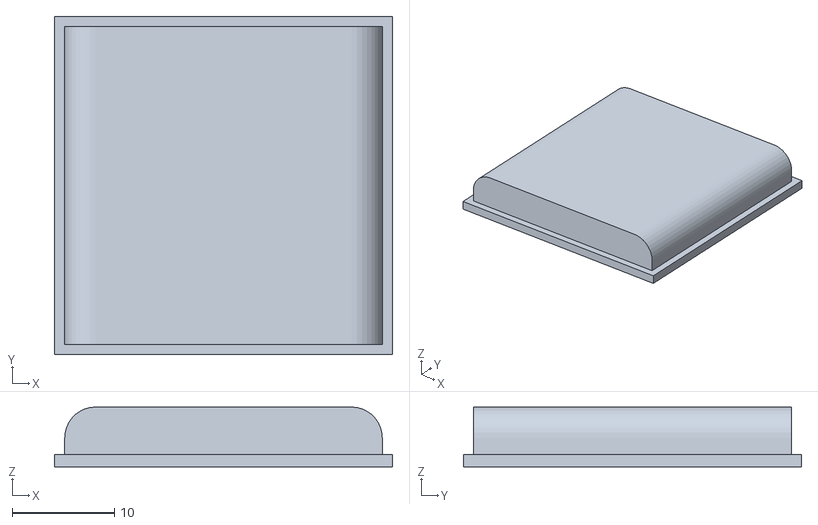
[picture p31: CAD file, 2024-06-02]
Enclosure/Pioneer/1mm PCB/Spoke_Pioneer_Cap_1.0mm.stl
33.0 x 33.0 x 5.85

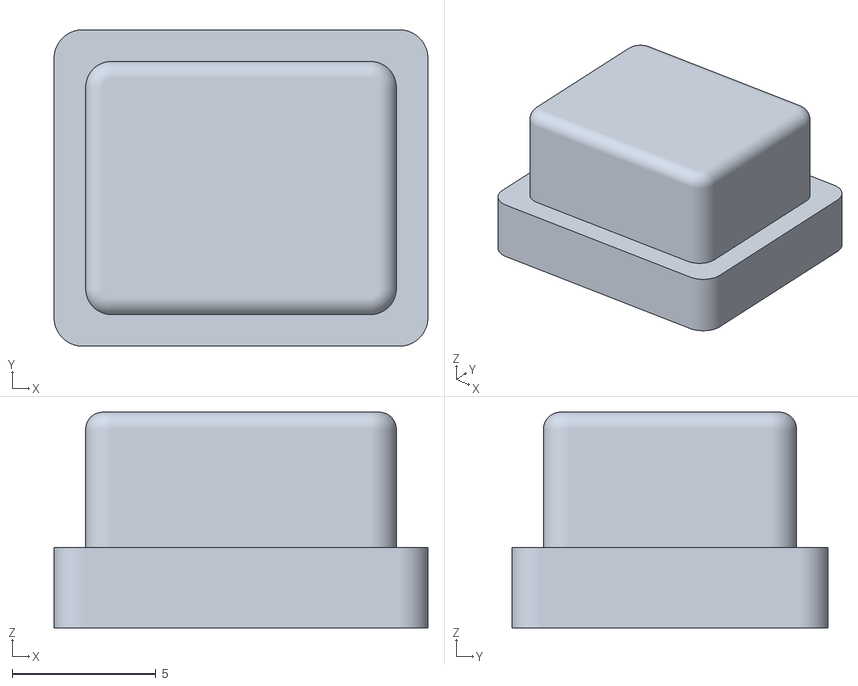
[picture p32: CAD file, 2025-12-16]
Enclosure/Endeavour/1.6mm PCB/button.stl
13.0 x 11.0 x 7.50

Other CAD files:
Enclosure/Enterprise/1mm PCB/Spoke_Enterprise_Bot_1.0mm.stl
Enclosure/Voyager/1mm PCB/Spoke_Voyager_Bot_1.0mm.stl

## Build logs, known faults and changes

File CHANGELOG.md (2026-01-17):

# Release HW Rev.2.1 17-Jan-2026
Major improvements keeping all HW revisions support

Implemented:
- Fixed power stall issue by swapping PWR_HOLD and RF_TXEN pins at MCU
- Fixed BLE UART module stuck in configuration mode
- Reduced Buzzer drive type from differential to single-ended
- Supported both: passive piezo and passive magnetic buzzers
- Added PWM-mode LCD backlight control
- Added separate ALARM button
- Added TU10-F QUESCAN SMD GPS module as an alternative
- Connected GPS receiver to MUX channel-4 for debug access
- Updated SMA footprint to fit both: 6.35 and 9.52 mm width connectors
- LEDs moved to the right to align with mounting hole
- Commented the schematic on components optional placement
- Other minor fixes

Known issues & limitations:
- No known issues

# Release FW Rev.5.0 (for HW Rev.1.x, Rev. 2.0, Rev 2.1) 06-Jan-2026 
All HW versions support, 868 MHz band with 1% duty cycle compliance, new packet format and lots of fixes and improvements

Implemented:
- Added support of the Spoke HW Rev.2.x
- Unified FW for all HW versions
- FW configuration is done at compile-time through defines in "config.h"
- PWM-controlled LCD backligh for Spoke HW Rev.2.x
- Single-ended PWM-controled passive buzzer drive for Spoke HW Rev.2.x
- PWR_HOLD line fix for Spoke HW Rev.2.x by swapping with RF_TXEN
- Separate BTN_ALARM line for alarm button for Spoke HW Rev.2.x
- Added 868 MHz band support for E22-900M22S radio module
- Added +14 dBm output power setting
- Added 120 sec update interval
- Updated packet format to 13 bytes with LDRO enabled
- Extended to POWER menu two-collumns
- Added DIAG menu with debug and test information
- Switching USB-UART/BLE-UART from menu
- Reading LoRa SNR instead of RSSI
- Removed GPS baud setting from menu
- Updated console-reports data sturcutre
- Implemented Kalman filter for accelerometer Z and magnetometed X, Y channels
- Minor and major fixes everywhere
- Refactoring for better code perception

Known issues & limitations:
- This FW version is incompatible over-the-air with previous FW versions because of different radio packet structure
- GPS NMEA parsing at 115200 baud may fail due to insufficient buffer size

# Release HW Rev.2.0 20-Sep-2025
Added USB Type C, USB-UART converter, UART-BLE Module, new LCD, DC/DC regulator

Implemented:
- New PCB size 100 x 50 mm
- Type C USB with CP2102N-28pin USB-UART converter
- UART-BLE connectivity by E104-BT5005A module
- Multiplexer to switch between USB and BLE
- New monochrome LCD with ST7567 controller
- DC/DC regulator LM3671MF instead of linear
- BOOT button to run the STM32 UART bootloader
- SMA connector for LoRa antenna
- MCU crystal in 3225 package
- 0603 components everywhere
- 3 mm TH LEDs
- MCU lines kept the same assignment as in HW Rev.1.x. for back-compatibility

Known issues & limitations:
- When no FW flashed (erased MCU) the PWR_HOLD line is held high by an internal JTDI pull-up resistor, so the device power does not switch off when power button gets released; battery disconnect is required
- BLE UART hangs in configuration mode because of logic levels conflict at MODE pin 

# Release FW Rev.4.0 (for HW Rev.1.x) 12-Apr-2025 
New look, compass with calibration, more settings & stabilization

Implemented:
- Dozens of bug fixes
- Revised interface, icons
- Added beep mute feature while scrolling devices
- Added GPS baud setting
- Implemented interactive compass calibration from menu
- Magnetic and True north icons
- Implemented navigational data output in Base64 through console
- Enabled watchdog
- Implemented periph. clock gating
- Improved uptime counter accuracy
- Changed battery level thresholds
- Added jump to bootloader at power up
- Changed optimization level to reduce flash usage

Known issues & limitations:
- GPS NMEA parsing at 115200 baud may fail due to insufficient buffer size

# Release HW Rev.1.2 02-Jun-2024 
Improvements

Implemented:
- Moved GPS module 2 mm down to align with buttons center
- Added text captions for GPS lines
- Updated stack-up to 1.6 mm overall thickness

Known issues & limitations:
- No known issues

# Release HW Rev.1.1 28-Jan-2024 
Fix of the HW release 1

Implemented:
- TEMP pin of the TP4056 connected to the GND directly

Known issues & limitations:
- No known issues

# Release FW Rev.3.0 (for HW Rev.1.0) 28-Jan-2024 
Switch to LoRa modulation, new TDMA approach, minor fixes

Implemented:
- LoRa modulation: SF12, BW125, CR 4/8, Header off, CRC
- TDMA approach: timeslot each even second (0, 2, 4...), RX/TX in 900 ms after PPS interrupt based on NMEA parsed in the same slot
- Other minor fixes

Known issues & limitations:
- Might be not stable, need to be tested for a long run

# Release FW Rev.2.0 (for HW Rev.1.0) 21-Nov-2023 
Lots of fixes, power consumption improvements, changes in apperance

Implemented:
- Reduced power consumption: MCU sleep mode, GPS aggressive 1 Hz mode via UBX configuration, PPS led reduced duty cycle
- Fix ADC battery readings; using internal reference for measurements
- Fix LCD buffer clear isuue when the update is ongoing
- Add device hard switch off at 2.8 V battery voltage
- Add more info for "reset to default" menu
- Add GPS configuration reset upon "reset to default"
- Change loading sequence; add infromation output to LCD for debug

Known issues & limitations:
- No known issues

# Release FW Rev.1.0 (for HW Rev.1.0) 01-Nov-2023 
The very first release of the firmware. Lots of imperfections and weak spots in code, as well as some minor bugs, but correctly working HW and SW with no major issues. 

Implemented:
- GPS NMEA parsing
- Radio communication, GFSK 1200 bps
- Interface and menu
- 4 memory points
- 2D compass with calibration and compensation

Known issues & limitations:
- ADC battery readings are incorrect below 3.3 V battery voltage due to Vref = VCC

# Release HW Rev.1.0 26-Mar-2023 
The very first release of the hardware. 

Implemented:
- See schematic

Known issues & limitations:
- TEMP pin of the TP4056 must be connected to the GND directly to disable temp protection feature. Cut the trace between U5 pin 1 and R8; then connect the pin 1 to GND.

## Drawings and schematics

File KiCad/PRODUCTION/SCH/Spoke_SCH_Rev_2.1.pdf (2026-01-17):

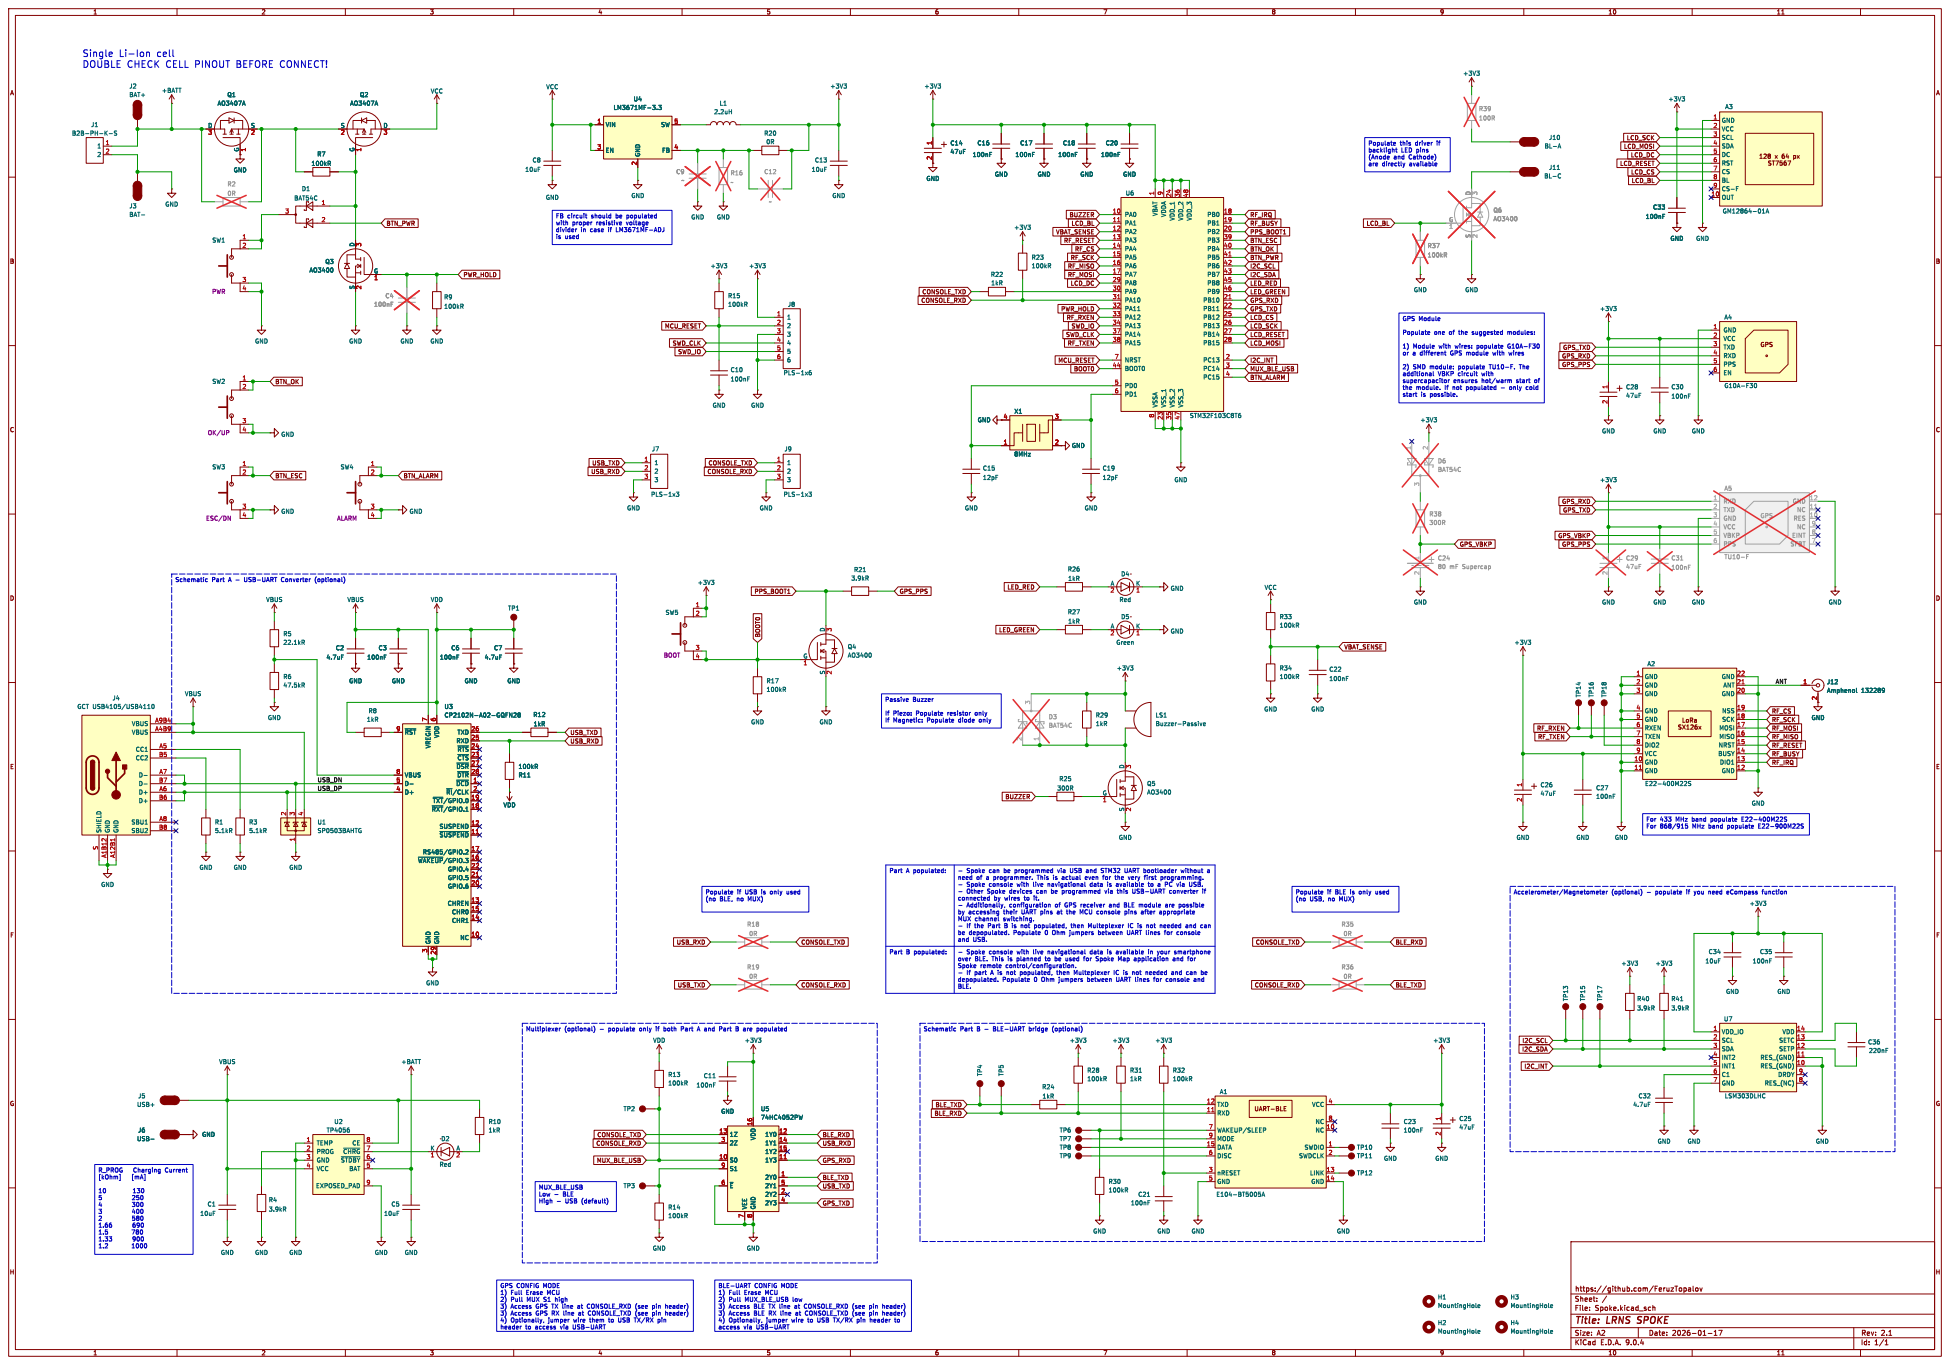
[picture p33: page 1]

Single Li-Ion cell
DOUBLE CHECK CELL PINOUT BEFORE CONNECT! GND Q1 AO3407AG

divider in case if LM3671MF-ADJ

1 D3BAT54C GND GND GND GND

6 GND 29 TXD 26 RXD 25 ~{RTS} 24 ~{CTS} 23 ~{DSR} 27 ~{DTR} 28 ~{DCD}1 ~{RI}/CLK2 ~{TXT}/GPIO.019 ~{RXT}/GPIO.118 SUSPEND 12 ~{SUSPEND}11 RS485/GPIO.2 17 ~{WAKEUP}/GPIO.316 GPIO.4 22 GPIO.5 21 GPIO.6 20 CHREN 13 CHR0 15 CHR1 14 NC 10 U3 CP2102N-A02-GQFN28

S GND A1B12 GND A12B1 VBUS A9B4 VBUS A4B9 CC1 A5 CC2 B5 D- A7 D- B7 D+ A6 D+ B6 SBU1 A8 SBU2 B8

6 GND 29 TXD 26 RXD 25 ~{RTS} 24 ~{CTS} 23 ~{DSR} 27 ~{DTR} 28 ~{DCD}1 ~{RI}/CLK2 ~{TXT}/GPIO.019 ~{RXT}/GPIO.118 SUSPEND 12 ~{SUSPEND}11 RS485/GPIO.2 17 ~{WAKEUP}/GPIO.316 GPIO.4 22 GPIO.5 21 GPIO.6 20 CHREN 13 CHR0 15 CHR1 14 NC 10 R12

header to access via USB-UART MUX_BLE_USB

1) Full Erase MCU
2) Pull MUX S1 high
3) Access GPS TX line at CONSOLE_RXD (see pin header)
3) Access GPS RX line at CONSOLE_TXD (see pin header)

2) Pull MUX_BLE_USB low
3) Access BLE TX line at CONSOLE_RXD (see pin header)
3) Access BLE RX line at CONSOLE_TXD (see pin header)

File: Spoke.kicad_sch Sheet: / https://github.com/FeruzTopalov

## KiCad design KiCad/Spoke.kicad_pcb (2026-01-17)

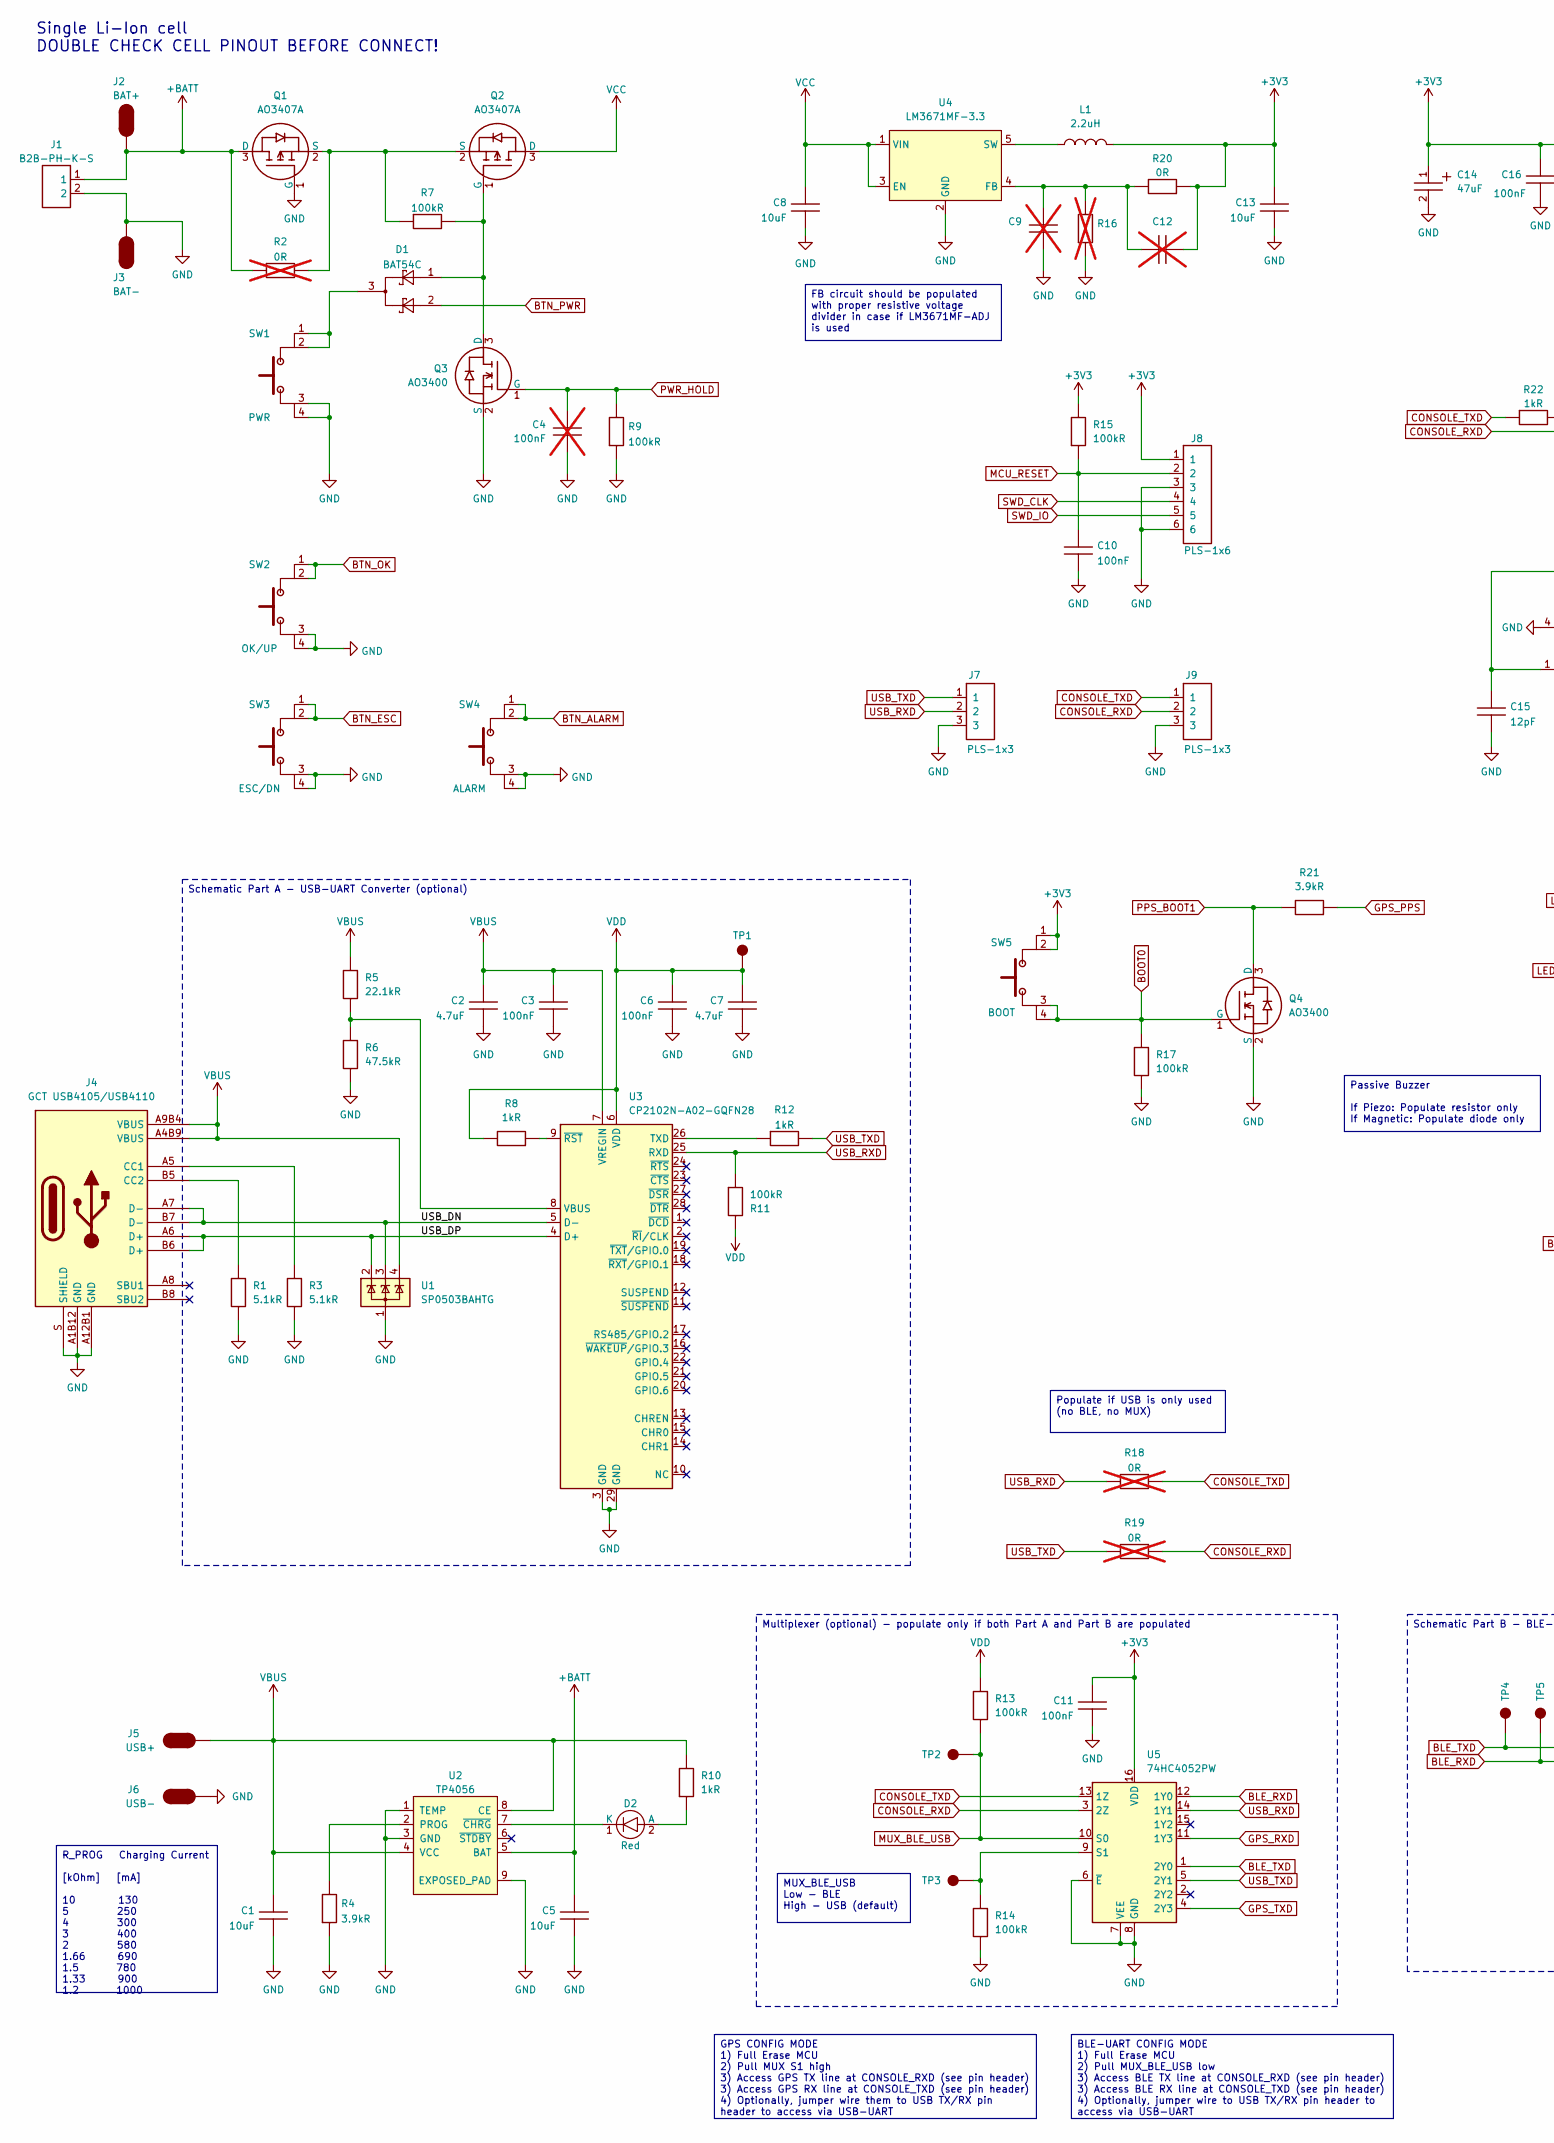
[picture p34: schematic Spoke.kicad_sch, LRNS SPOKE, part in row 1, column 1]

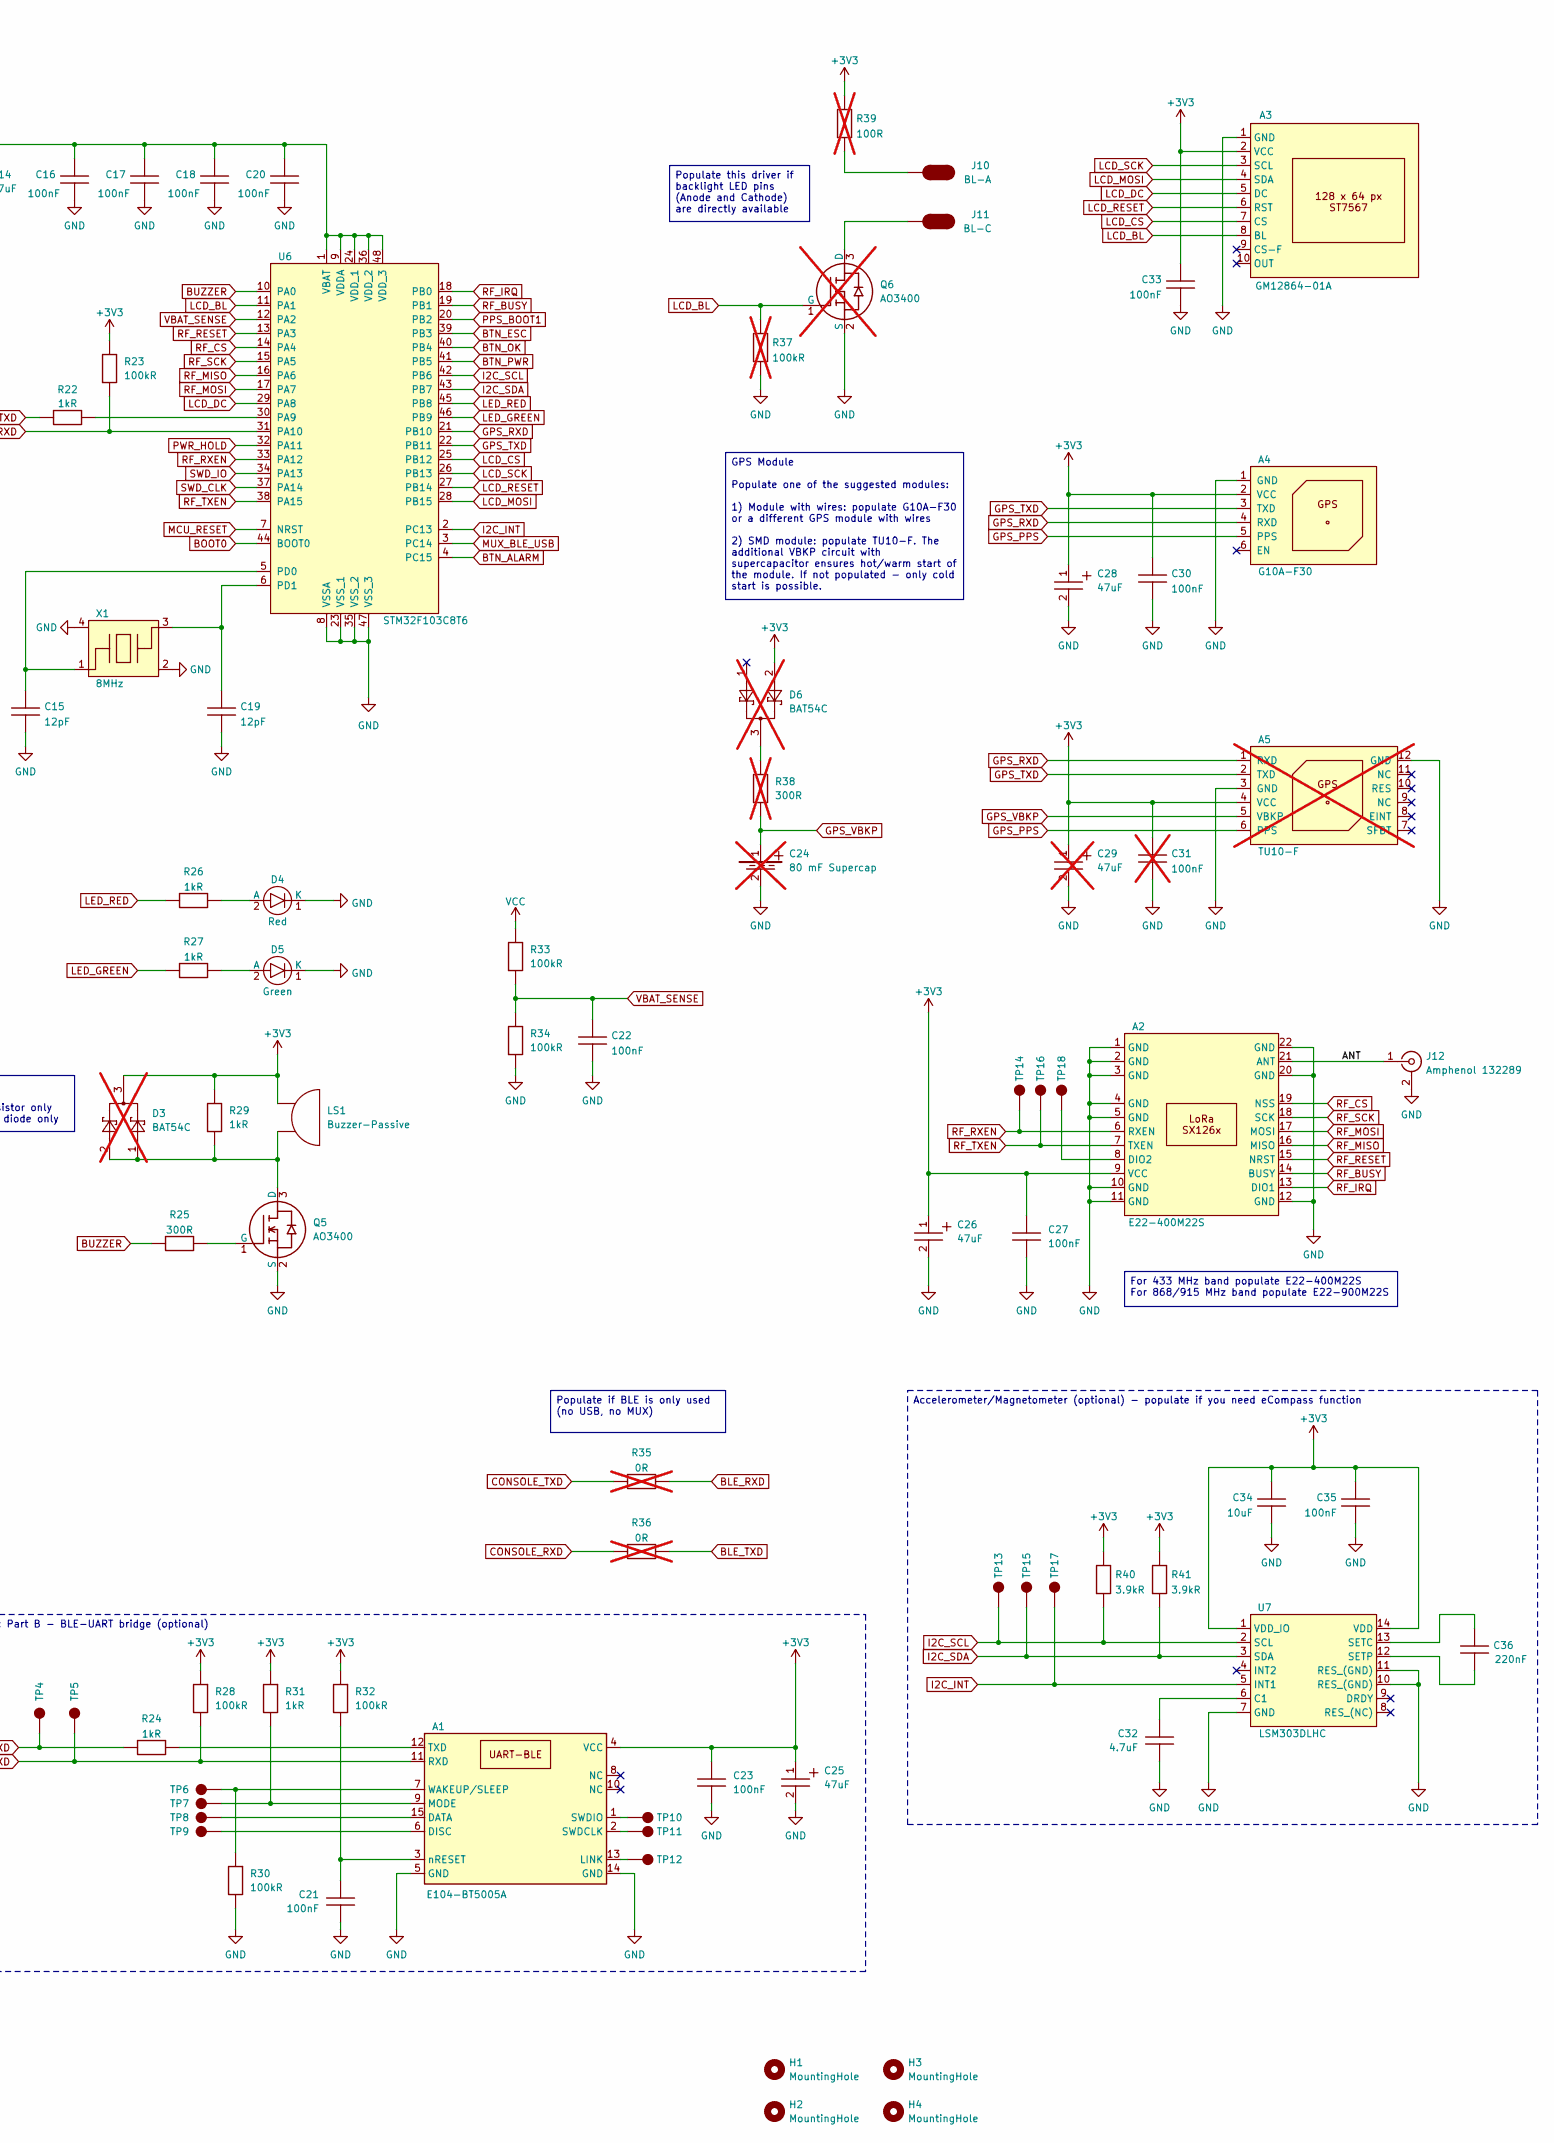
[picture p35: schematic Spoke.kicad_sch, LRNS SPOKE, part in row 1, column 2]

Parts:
A1: E104-BT5005A
A2: E22-400M22S; E22
A3: GM12864-01A
A4: G10A-F30
A5: TU10-F; not fitted
C1, C5, C8, C13, C34: 10uF; C1206
C2, C7, C32: 4.7uF; C0805
C3, C6, C10, C11, C16, C17, C18, C20, C21, C22, C23, C27, C30, C33, C35: 100nF; C0603
C4, C31: 100nF; C0603; not fitted
C9, C12: C0603; not fitted
C14, C25, C26, C28: 47uF; C_tantA
C15, C19: 12pF; C0603
C24: 80 mF Supercap; XH414HG-IV01E; not fitted
C29: 47uF; C_tantA; not fitted
C36: 220nF; C0603
D1: BAT54C; SOT-23
D2, D4: Red; LED_3mm
D3, D6: BAT54C; SOT-23; not fitted
D5: Green; LED_3mm
H1, H2, H3, H4: MountingHole; MountingHole_3.2mm_M3
J1: B2B-PH-K-S; B2B-PH-2.0
J2: BAT+; Pad_oval
J3: BAT-; Pad_oval
J4: GCT USB4105/USB4110; USB_C_16p_GCT4105
J5: USB+; Pad_oval
J6: USB-; Pad_oval
J7, J9: PLS-1x3; Header_1x3
J8: PLS-1x6; Header_1x6
J10: BL-A; Pad_oval
J11: BL-C; Pad_oval
J12: Amphenol 132289; SMA
L1: 2.2uH; L1616
LS1: Buzzer-Passive; Buzzer
Q1, Q2: AO3407A; SOT-23
Q3, Q4, Q5: AO3400; SOT-23
Q6: AO3400; SOT-23; not fitted
R1, R3: 5.1kR; R0603
R2, R18, R19, R35, R36: 0R; R0603; not fitted
R4, R21, R40, R41: 3.9kR; R0603
R5: 22.1kR; R0603
R6: 47.5kR; R0603
R7, R9, R11, R13, R14, R15, R17, R23, R28, R30, R32, R33, R34: 100kR; R0603
R8, R10, R12, R22, R24, R26, R27, R29, R31: 1kR; R0603
R16: R0603; not fitted
R20: 0R; R0603
R25: 300R; R0603
R37: 100kR; R0603; not fitted
R38: 300R; R0603; not fitted
R39: 100R; R1206; not fitted
SW1, SW2, SW3, SW4, SW5: Button_6x6
TP1, TP2, TP3, TP4, TP5, TP6, TP7, TP8, TP9, TP10, TP11, TP12, TP13, TP14, TP15, TP16, TP17, TP18: Pad-Round; Pad_round
U1: SP0503BAHTG; SOT-143
U2: TP4056; SOIC-8-EP
U3: CP2102N-A02-GQFN28; QFN-28
U4: LM3671MF-3.3; SOT-23-5
U5: 74HC4052PW; TSSOP-16
U6: STM32F103C8T6; LQFP-48
U7: LSM303DLHC; LGA-14
X1: 8MHz; Xtal_3225

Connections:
+3V3: A1.4 (VCC), A2.9 (VCC), A3.2 (VCC), A4.2 (VCC), A5.4 (VCC), C11.1, C12.2, C13.2, C14.1, C16.1, C17.1, C18.1, C20.1, C23.1, C25.1, C26.1, C27.1, C28.1, C29.1, C30.1, C31.1, C33.1, C34.2, C35.1, D3.3, D6.2, J8.1, L1.2, LS1.1, R15.2, R20.1, R23.2, R28.1, R29.2, R31.1, R32.1, R39.2, R40.2, R41.2, SW5.1, SW5.2, U5.16 (VDD), U6.1 (VBAT), U6.9 (VDDA), U6.24 (VDD_1), U6.36 (VDD_2), U6.48 (VDD_3), U7.1 (VDD_IO), U7.14 (VDD)
+BATT: C5.2, J1.1, J2.1, Q1.3 (D), R2.1, U2.5 (BAT)
/ANT: A2.21 (ANT), J12.1 (RF)
/USB_DN: J4.A7 (D-), J4.B7 (D-), U1.3 (K), U3.5 (D-)
/USB_DP: J4.A6 (D+), J4.B6 (D+), U1.2 (K), U3.4 (D+)
BLE_RXD: A1.11 (RXD), R28.2, R35.2, TP5.1, U5.12 (1Y0)
BLE_TXD: R24.1, R36.2, TP4.1, U5.1 (2Y0)
BOOT0: Q4.1 (G), R17.1, SW5.3 (2), SW5.4 (2), U6.44 (BOOT0)
BTN_ALARM: SW4.1, SW4.2, U6.4 (PC15)
BTN_ESC: SW3.1, SW3.2, U6.39 (PB3)
BTN_OK: SW2.1, SW2.2, U6.40 (PB4)
BTN_PWR: D1.2, U6.41 (PB5)
BUZZER: R25.1, U6.10 (PA0)
CONSOLE_RXD: J9.2, R19.1, R23.1, R36.1, U5.3 (2Z), U6.31 (PA10)
CONSOLE_TXD: J9.1, R18.1, R22.1, R35.1, U5.13 (1Z)
GND: A1.5 (GND), A1.14 (GND), A2.1 (GND), A2.2 (GND), A2.3 (GND), A2.4 (GND), A2.5 (GND), A2.10 (GND), A2.11 (GND), A2.12 (GND), A2.20 (GND), A2.22 (GND), A3.1 (GND), A4.1 (GND), A5.3 (GND), A5.12 (GND), C1.1, C2.1, C3.1, C4.2, C5.1, C6.1, C7.1, C8.1, C9.2, C10.2, C11.2, C13.1, C14.2, C15.2, C16.2, C17.2, C18.2, C19.2, C20.2, C21.2, C22.2, C23.2, C24.2, C25.2, C26.2, C27.2, C28.2, C29.2, C30.2, C31.2, C32.1, C33.2, C34.1, C35.2, D4.1 (K), D5.1 (K), J1.2, J3.1, J4.A1B12 (GND), J4.A12B1 (GND), J4.S (SHIELD), J6.1, J7.3, J8.3, J8.6, J9.3, J12.2 (GND), Q1.1 (G), Q3.2 (S), Q4.2 (S), Q5.2 (S), Q6.2 (S), R1.2, R3.2, R4.1, R6.2, R9.1, R14.2, R16.1, R17.2, R30.2, R34.1, R37.1, SW1.3 (2), SW1.4 (2), SW2.3 (2), SW2.4 (2), SW3.3 (2), SW3.4 (2), SW4.3 (2), SW4.4 (2), U1.1 (A), U2.1 (TEMP), U2.3 (GND), U2.9 (EXPOSED_PAD), U3.3 (GND), U3.29 (GND), U4.2 (GND), U5.6 (~E), U5.7 (VEE), U5.8 (GND), U6.8 (VSSA), U6.23 (VSS_1), U6.35 (VSS_2), U6.47 (VSS_3), U7.7 (GND), U7.10 (RES_(GND)), U7.11 (RES_(GND)), X1.2, X1.4
GPS_PPS: A4.5 (PPS), A5.6 (PPS), R21.1
GPS_RXD: A4.4 (RXD), A5.1 (RXD), U5.11 (1Y3), U6.21 (PB10)
GPS_TXD: A4.3 (TXD), A5.2 (TXD), U5.4 (2Y3), U6.22 (PB11)
GPS_VBKP: A5.5 (VBKP), C24.1, R38.1
I2C_INT: TP17.1, U6.2 (PC13), U7.5 (INT1)
I2C_SCL: R40.1, TP13.1, U6.42 (PB6), U7.2 (SCL)
I2C_SDA: R41.1, TP15.1, U6.43 (PB7), U7.3 (SDA)
LCD_BL: A3.8 (BL), Q6.1 (G), R37.2, U6.11 (PA1)
LCD_CS: A3.7 (CS), U6.25 (PB12)
LCD_DC: A3.5 (DC), U6.29 (PA8)
LCD_MOSI: A3.4 (SDA), U6.28 (PB15)
LCD_RESET: A3.6 (RST), U6.27 (PB14)
LCD_SCK: A3.3 (SCL), U6.26 (PB13)
LED_GREEN: R27.1, U6.46 (PB9)
LED_RED: R26.1, U6.45 (PB8)
MCU_RESET: C10.1, J8.2, R15.1, U6.7 (NRST)
MUX_BLE_USB: R13.2, TP2.1, U5.10 (S0), U6.3 (PC14)
unnamed: A1.15 (DATA), TP8.1
unnamed: A1.6 (DISC), TP9.1
unnamed: A1.13 (LINK), TP12.1
unnamed: A1.9 (MODE), R31.2, TP7.1
unnamed: A1.2 (SWDCLK), TP11.1
unnamed: A1.1 (SWDIO), TP10.1
unnamed: A1.12 (TXD), R24.2
unnamed: A1.7 (WAKEUP/SLEEP), R30.1, TP6.1
unnamed: A1.3 (nRESET), C21.1, R32.2
unnamed: A2.8 (DIO2), TP18.1
unnamed: D1.3, SW1.1, SW1.2
unnamed: D2.2 (A), R10.1
unnamed: D2.1 (K), U2.7 (~CHRG)
unnamed: D4.2 (A), R26.2
unnamed: D5.2 (A), R27.2
unnamed: D6.3, R38.2
unnamed: J4.A5 (CC1), R3.1
unnamed: J4.B5 (CC2), R1.1
unnamed: J10.1, R39.1
unnamed: Q1.2 (S), Q2.2 (S), R2.2, R7.1
unnamed: D1.1, Q2.1 (G), Q3.3 (D), R7.2
unnamed: D3.1, D3.2, LS1.2, Q5.3 (D), R29.1
unnamed: Q5.1 (G), R25.2
unnamed: J11.1, Q6.3 (D)
unnamed: R4.2, U2.2 (PROG)
unnamed: R12.1, U3.26 (TXD)
unnamed: R5.2, R6.1, U3.8 (VBUS)
unnamed: R8.1, U3.9 (~RST)
unnamed: C9.1, C12.1, R16.2, R20.2, U4.4 (FB)
unnamed: L1.1, U4.5 (SW)
unnamed: R14.1, TP3.1, U5.9 (S1)
unnamed: R22.2, U6.30 (PA9)
unnamed: C15.1, U6.5 (PD0), X1.1
unnamed: C19.1, U6.6 (PD1), X1.3
unnamed: C32.2, U7.6 (C1)
unnamed: C36.1, U7.13 (SETC)
unnamed: C36.2, U7.12 (SETP)
PPS_BOOT1: Q4.3 (D), R21.2, U6.20 (PB2)
PWR_HOLD: C4.1, Q3.1 (G), R9.2, U6.32 (PA11)
RF_BUSY: A2.14 (BUSY), U6.19 (PB1)
RF_CS: A2.19 (NSS), U6.14 (PA4)
RF_IRQ: A2.13 (DIO1), U6.18 (PB0)
RF_MISO: A2.16 (MISO), U6.16 (PA6)
RF_MOSI: A2.17 (MOSI), U6.17 (PA7)
RF_RESET: A2.15 (NRST), U6.13 (PA3)
RF_RXEN: A2.6 (RXEN), TP14.1, U6.33 (PA12)
RF_SCK: A2.18 (SCK), U6.15 (PA5)
RF_TXEN: A2.7 (TXEN), TP16.1, U6.38 (PA15)
SWD_CLK: J8.4, U6.37 (PA14)
SWD_IO: J8.5, U6.34 (PA13)
USB_RXD: J7.2, R11.1, R18.2, U3.25 (RXD), U5.14 (1Y1)
USB_TXD: J7.1, R12.2, R19.2, U5.5 (2Y1)
VBAT_SENSE: C22.1, R33.1, R34.2, U6.12 (PA2)
VBUS: C1.2, C2.2, C3.2, J4.A4B9 (VBUS), J4.A9B4 (VBUS), J5.1, R5.1, R10.2, U1.4 (K), U2.4 (VCC), U2.8 (CE), U3.7 (VREGIN)
VCC: C8.2, Q2.3 (D), R33.2, U4.1 (VIN), U4.3 (EN)
VDD: C6.2, C7.2, R8.2, R11.2, R13.1, TP1.1, U3.6 (VDD)

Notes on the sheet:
Single Li-Ion cell DOUBLE CHECK CELL PINOUT BEFORE CONNECT!
Passive Buzzer If Piezo: Populate resistor only If Magnetic: Populate diode only
FB circuit should be populated with proper resistive voltage divider in case if LM3671MF-ADJ is used
GPS Module Populate one of the suggested modules: 1) Module with wires: populate G10A-F30 or a different GPS module with wires 2) SMD module: populate TU10-F. The additional VBKP circuit with supercapacitor ensures hot/warm start of the module. If not populated - only cold start is possible.
GPS CONFIG MODE 1) Full Erase MCU 2) Pull MUX S1 high 3) Access GPS TX line at CONSOLE_RXD (see pin header) 3) Access GPS RX line at CONSOLE_TXD (see pin header) 4) Optionally, jumper wire them to USB TX/RX pin header to access via USB-UART
Schematic Part B - BLE-UART bridge (optional)
Populate if BLE is only used (no USB, no MUX)
R_PROG Charging Current [kOhm] [mA] 10 130 5 250 4 300 3 400 2 580 1.66 690 1.5 780 1.33 900 1.2 1000
MUX_BLE_USB Low - BLE High - USB (default)
Populate if USB is only used (no BLE, no MUX)
Schematic Part A - USB-UART Converter (optional)
BLE-UART CONFIG MODE 1) Full Erase MCU 2) Pull MUX_BLE_USB low 3) Access BLE TX line at CONSOLE_RXD (see pin header) 3) Access BLE RX line at CONSOLE_TXD (see pin header) 4) Optionally, jumper wire to USB TX/RX pin header to access via USB-UART
Populate this driver if backlight LED pins (Anode and Cathode) are directly available
Accelerometer/Magnetometer (optional) - populate if you need eCompass function
Multiplexer (optional) - populate only if both Part A and Part B are populated
For 433 MHz band populate E22-400M22S For 868/915 MHz band populate E22-900M22S

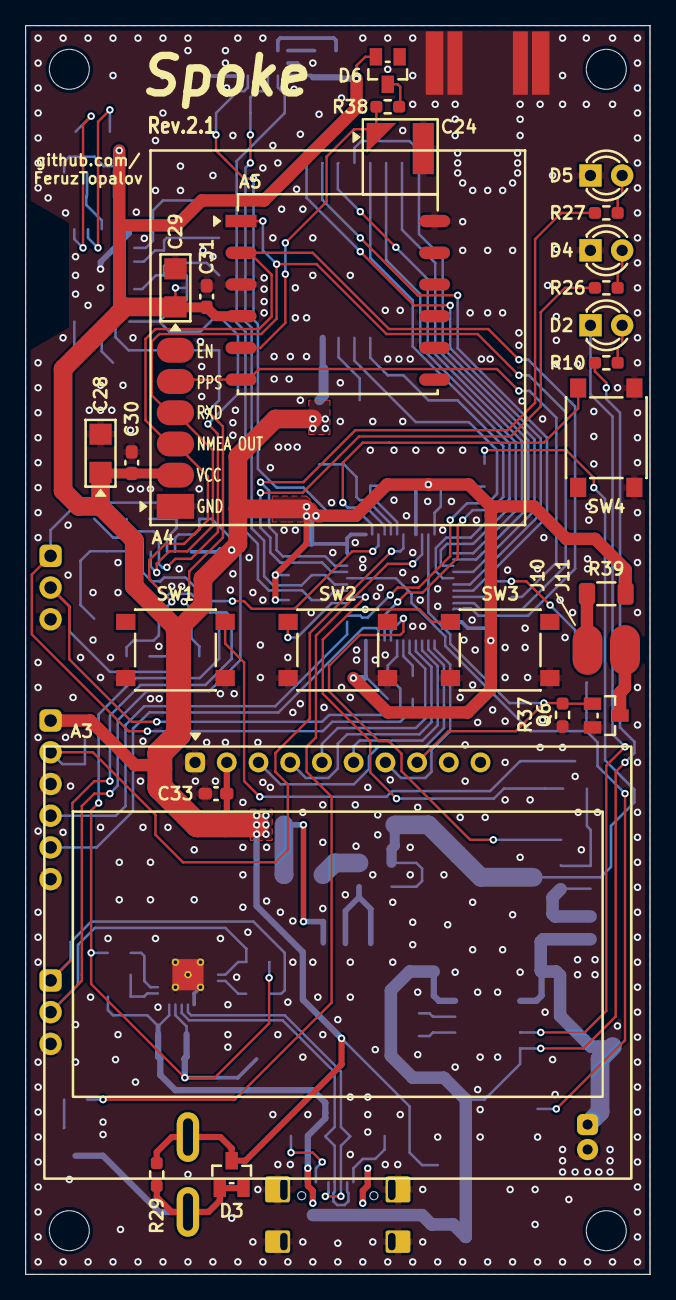
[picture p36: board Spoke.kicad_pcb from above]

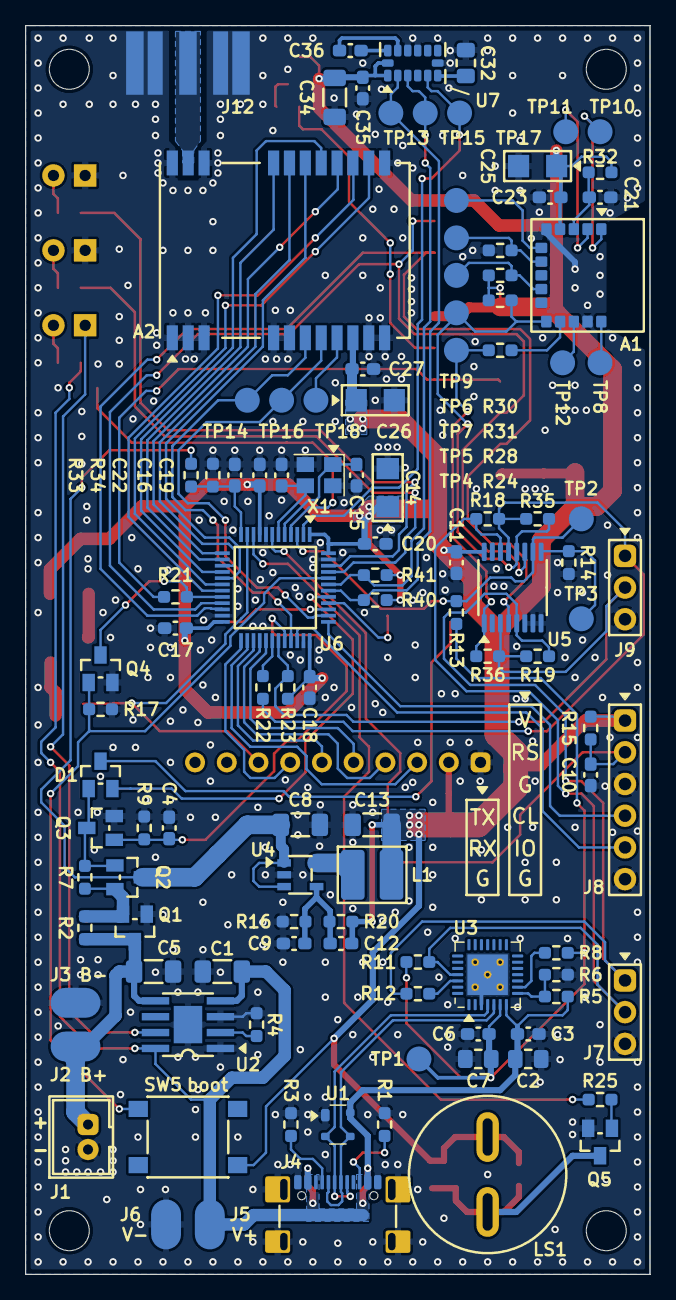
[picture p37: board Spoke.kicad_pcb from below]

Board: 2 copper layers, 50.0 x 100.0 mm, 143 parts (111 on the bottom side), 89 nets.

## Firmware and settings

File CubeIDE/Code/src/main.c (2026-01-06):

/*
	SPOKE
    
    file: main.c
*/



#include <string.h>
#include "stm32f10x.h"
#include "main.h"
#include "gpio.h"
#include "spi.h"
#include "lcd.h"
#include "service.h"
#include "lcd_bitmaps.h"
#include "timer.h"
#include "buttons.h"
#include "menu.h"
#include "memory.h"
#include "settings.h"
#include "lrns.h"
#include "points.h"
#include "uart.h"
#include "gps.h"
#include "radio.h"
#include "sx126x.h"
#include "i2c.h"
#include "compass.h"
#include "sensors.h"
#include "adc.h"
#include "config.h"



void setup_interrupt_priorities(void);



struct main_flags_struct main_flags = {0};
struct gps_num_struct *p_gps_num;
struct settings_struct *p_settings;
struct devices_struct **pp_devices;



//TIMERS
uint32_t uptime_cntr = 0;
uint32_t nmea_overflow_cntr = 0;
uint32_t pps_absolute_cntr = 0;
uint32_t pps_continuous_cntr = 0;
uint32_t lora_tx_cycles_cntr = 0;
uint32_t lora_rx_cycles_cntr = 0;
uint32_t lora_crc_err_cntr = 0;
uint32_t lora_rx_timeouts_cntr = 0;

//OTHER
uint8_t *p_update_interval_values;

uint8_t button_code = 0;
uint8_t processing_button = 0;

uint8_t radio_action;



//PROGRAM
int main(void)
{
    gpio_init(); //for SPI and backlight pins
    manage_power();
    spi_init();	//for LCD operation
    timers_init(); //for LCD PWM backlight
    settings_load(); //for saved backlight setting
    setup_interrupt_priorities();
    __enable_irq();	//for LCD DMA operation
    lcd_init();
    process_pending_save_default(); //if it was requested upon settings_load()

    //start screen
    lcd_bitmap(&startup_screen[0]);
    lcd_update();
    delay_cyc(800000);

    lcd_print_only(0, 0, "uart..");
    uart_init();

    lcd_print_only(0, 0, "adc..");
    adc_init();
    adc_start_bat_voltage_reading();

    lcd_print_only(0, 0, "i2c..");
    i2c_init();

    lcd_print_only(0, 0, "radio..");
    rf_init();

    lcd_print_only(0, 0, "core..");
    init_lrns();

    lcd_print_only(0, 0, "gps..");
    gps_init();

    lcd_print_only(0, 0, "compass..");
    init_compass();

    lcd_print_only(0, 0, "interrupts..");
    ext_int_init();
    enable_buttons_interrupts();

    lcd_print_only(0, 0, "mem points..");
    init_memory_points();

    lcd_print_only(0, 0, "menu..");
    init_menu();



    //initial variables
    p_settings = get_settings();
    p_gps_num = get_gps_num();
    p_update_interval_values = get_update_interval_values();
    pp_devices = get_devices();



    make_a_beep();	//end of device loading
    draw_current_menu();

    while (1)
    {
    	//Scan Keys
    	if (main_flags.buttons_scanned == 1)
    	{
    		main_flags.buttons_scanned = 0;
			change_menu(button_code);
			reset_backlight_counter();
			main_flags.update_screen = 1;
    	}



        //Parse GPS after PPS interrupt or UART DMA overflow
        if (main_flags.parse_nmea == 1)
        {
            main_flags.parse_nmea = 0;

            if (parse_gps() == 1)
            {
				if 	(main_flags.pps_synced == 1)		//ready to txrx when pps exists & data is valid
				{
					if (p_gps_num->status == GPS_DATA_VALID)
					{
						main_flags.start_radio = 1;
					}
				}
				else
				{
					main_flags.nmea_parsed_only = 1; //show results after successful parsing //only if pps does not exist; otherwise screen_update will be set after frame_end
				}
            }
        }



        //After each second
        if (main_flags.tick_1s == 1)
        {
        	main_flags.tick_1s = 0;

        	decrement_backlight_counter();

            adc_check_bat_voltage();
            if (is_battery_critical())
            {
            	lcd_print_only(2, 2, "BATTERY LOW!");
            	delay_cyc(600000);
            	release_power();	//turn off immediately
            }

			calc_timeout(uptime_cntr);
            if (main_flags.pps_synced == 0) 	//when no PPS we still need timeout alarming once in a sec (mostly for our device to alarm about no PPS)
            {
            	main_flags.do_beep += check_any_alarm_fence_timeout();
            	main_flags.do_beep += is_battery_low();
            }
        }



        //Checks after receiving a packet from a device; performing beep
        if (main_flags.process_all == 1)
        {
        	main_flags.process_all = 0;
        	process_all_devices();

        	calc_fence();
        	calc_timeout(uptime_cntr);
        	main_flags.do_beep += check_any_alarm_fence_timeout();
        	main_flags.do_beep += is_battery_low();
        	main_flags.update_screen = 1;

        	report_to_console(); //send fresh devices data to console
        }


        if (main_flags.nmea_parsed_only == 1)	//only nmea parsed (like time and date, num of sats) while no pps exists
        {
        	main_flags.nmea_parsed_only = 0;
        	main_flags.update_screen = 1;

        	report_to_console(); //send fresh devices data to console
        }



    	if (main_flags.process_compass == 1)
		{
    		main_flags.process_compass = 0;

    		if (read_compass())
    		{
    			main_flags.update_screen = 1;
    		}
		}



    	//screen update (only once in a main cycle)
    	if (main_flags.update_screen == 1)
		{
    		if (!get_lcd_busy())
    		{
    			main_flags.update_screen = 0;
    			draw_current_menu();
    		}
		}



		//beep on alarm/fence/timeout/lowbatt
    	if (main_flags.do_beep != 0)
		{
    		main_flags.do_beep = 0;
    		make_a_beep();
		}


    	//Reload watchdog
    	reload_watchdog();

        //Wait for interrupt
        __WFI();



    } //while(1) end
} //main() end



//DMA UART RX overflow
void DMA1_Channel3_IRQHandler(void)
{
	DMA1->IFCR = DMA_IFCR_CGIF3;     //clear all interrupt flags for DMA channel 3

    uart3_dma_stop();
    backup_and_clear_uart_buffer();
    uart3_dma_restart();

    nmea_overflow_cntr++;
    pps_continuous_cntr = 0;
    main_flags.pps_synced = 0;
    main_flags.parse_nmea = 1;

}



//GPS PPS Interrupt
void EXTI2_IRQHandler(void)
{

	EXTI->PR = EXTI_PR_PR2;			//clear interrupt

	uart3_dma_stop();				//drop the previous data; there will be new after this PPS
	clear_uart_buffer();
	uart3_dma_restart();

	pps_continuous_cntr++;
	pps_absolute_cntr++;

	if (pps_continuous_cntr > MIN_CONT_PPS)		//drop all possible "glitch" pps, or several first pps to get it stabilized
	{
		timer1_start_800ms();           //start gps acquire timer
		main_flags.pps_synced = 1;
	}

}



//Radio Interrupt (PayloadReady or PacketSent)
void EXTI0_IRQHandler(void)
{
    EXTI->PR = EXTI_PR_PR0;         //clear interrupt

	uint16_t current_radio_status = rf_get_irq_status();	//Process the radio interrupt
	rf_clear_irq();		//clear all flags

	if (current_radio_status & IRQ_RX_DONE)	//Packet received
	{
		main_flags.rx_state = 0;
		led_green_off();

		rf_workaround_15_3();	//run if rx timeout was used

		if (!(current_radio_status & IRQ_CRC_ERROR))	// if no CRC error
		{
			uint8_t rx_dev = 0;

			rf_get_rx_packet();
			rx_dev = parse_air_packet(uptime_cntr);   //parse air data from another device (which has ended TX in the current time_slot)
			if (rx_dev != NAV_OBJECT_NULL)
			{
				pp_devices[rx_dev]->lora_snr = rf_get_last_snr();	//read and save SNR
			}

			lora_rx_cycles_cntr++;
		}
		else if (current_radio_status & IRQ_CRC_ERROR)
		{
			lora_crc_err_cntr++;
		}
	}
	else if (current_radio_status & IRQ_TX_DONE)		//Packet transmission completed
	{
		main_flags.tx_state = 0;
		lora_tx_cycles_cntr++;
		led_green_off();
	}
	else if (current_radio_status & IRQ_RX_TX_TIMEOUT)	//RX timeout only, because TX timeout feature is not used at all
	{
		main_flags.rx_state = 0;
		lora_rx_timeouts_cntr++;
		led_green_off();
	}
}



//Timer1 GPS Acquire + Radio Run
void TIM1_UP_IRQHandler(void)
{
    TIM1->SR &= ~TIM_SR_UIF;                    //clear interrupt
    timer1_stop_reload();						//stop this timer

    if (timer1_get_intrvl_type() == TIMER1_INTERVAL_TYPE_LONG) //long interval 800 ms ended
    {

    	//parse NMEA, run short timer
    	timer1_start_100ms();

		uart3_dma_stop();					//fix the nmea data after last pps (800 ms ago)
		backup_and_clear_uart_buffer();
		uart3_dma_restart();				//restart for a case when no next PPS occur, then dma ovf will trigger
										//otherwise next PPS will reset dma again before the upcoming nmea data

    	main_flags.parse_nmea = 1;			//ask to parse

    }
    else if (timer1_get_intrvl_type() == TIMER1_INTERVAL_TYPE_SHORT) //short interval 100 ms ended, resulting 800 ms + 100 ms=900 ms after last pps
    {

    	//important: NMEA must be parsed before execution of this code
    	//start radio, run processing of all devices

    	if (main_flags.start_radio == 1)
    	{
    		main_flags.start_radio = 0;

    		radio_action = get_lrns_protocol_radio_action();

    		if (radio_action == LRNS_RADIO_ACTION_TX)
    		{
    			//tx
				fill_air_packet(uptime_cntr);
				if (rf_tx_packet())
				{
					main_flags.tx_state = 1;
					led_green_on();
				}
    		}
    		else if ((radio_action == LRNS_RADIO_ACTION_RX) || (radio_action == LRNS_RADIO_ACTION_RX_ACTIVE_DEV))
    		{
    			//rx
				if (rf_start_rx())
				{
					main_flags.rx_state = 1;

					if (radio_action == LRNS_RADIO_ACTION_RX_ACTIVE_DEV)	//blink green if going to receive from current navigate-to device
					{
						led_green_on();
					}
				}
    		}

    	    //after all do a re-calculate all
    	    main_flags.process_all = 1;
    	}
    }
}



//Scan buttons interval
void TIM3_IRQHandler(void)
{
	TIM3->SR &= ~TIM_SR_UIF;        //clear gating timer int

	if (main_flags.buttons_scanned == 0)	//if not scanned yet
	{
		button_code = scan_button(processing_button);
		if (button_code)
		{
			main_flags.buttons_scanned = 1;
		}
	}

}



//DOWN/ESC button interrupt
void EXTI3_IRQHandler(void)
{
	disable_buttons_interrupts();
	EXTI->PR = EXTI_PR_PR3;		//clear interrupt
	processing_button = BUTTON_DOWN_ESC_PB3;
	timer3_start();
}



//UP/OK button interrupt
void EXTI4_IRQHandler(void)
{
	disable_buttons_interrupts();
	EXTI->PR = EXTI_PR_PR4;		//clear interrupt
	processing_button = BUTTON_UP_OK_PB4;
	timer3_start();
}



//PWR button interrupt
void EXTI9_5_IRQHandler(void)
{
	disable_buttons_interrupts();
	EXTI->PR = EXTI_PR_PR5;		//clear interrupt
	processing_button = BUTTON_PWR_PB5;
	timer3_start();
}



void EXTI15_10_IRQHandler(void)
{
#ifdef SPLIT_PWM_BUZZER_BACKLIGHT
	if (EXTI->PR & EXTI_PR_PR15)	//Alarm button interrupt
	{
		enable_my_alarm();
		button_code = BTN_NO_ACTION;
		main_flags.buttons_scanned = 1; //fake buttons scanned event to light up backlight and update menu
		EXTI->PR = EXTI_PR_PR15;		//clear interrupt
	}
#endif

	if (EXTI->PR & EXTI_PR_PR13)	//ACC movement interrupt
	{
		set_acc_movement_flag(ACC_MOVEMENT_DETECTED);
		disable_acc_movement_interrupt();				//once movement is detected, switch interrupt off until the beginning of the next update interval
		EXTI->PR = EXTI_PR_PR13;		//clear interrupt
	}
}



//Console RX symbol
void USART1_IRQHandler(void)
{
    uint32_t uart_sr;
    uint8_t uart_rx_data;

    uart_sr = USART1->SR;   //read SR first

    if (uart_sr & USART_SR_RXNE)
    {
        uart_rx_data = USART1->DR;

        if (uart_rx_data == UART_CMD_CONSOLE_START)
        {
        	switch_console_reports(CONSOLE_REPORT_ENABLED);
        }
        else if (uart_rx_data == UART_CMD_CONSOLE_STOP)
        {
        	switch_console_reports(CONSOLE_REPORT_DISABLED);
        }
    }
    else if (uart_sr & (USART_SR_ORE | USART_SR_FE | USART_SR_NE | USART_SR_PE))
    {
        (void)USART1->DR;  // clear error flags performing a read SR and read DR sequence
    }
}



//Console UART TX DMA completed
void DMA1_Channel4_IRQHandler(void)
{
	DMA1->IFCR = DMA_IFCR_CGIF4;     //clear all interrupt flags for DMA channel 4
	uart1_dma_stop();
}



//End of beep
void SysTick_Handler(void)
{
	buzzer_pwm_stop();	//pwm
	systick_stop();	//gating
	led_red_off();
}



//Compass update interval
void TIM4_IRQHandler(void)
{
	TIM4->SR &= ~TIM_SR_UIF;        //clear gating timer int

	main_flags.process_compass = 1;
}



//DMA SPI2 TX LCD
void DMA1_Channel5_IRQHandler(void)
{
	DMA1->IFCR = DMA_IFCR_CGIF5;     //clear all interrupt flags for DMA channel 5

	spi2_dma_stop();
	cs_lcd_inactive();
	lcd_continue_update();
}



//Uptime counter (every 1 second)
void RTC_IRQHandler(void)
{
	RTC->CRL &= ~RTC_CRL_SECF;		//Clear interrupt

    uptime_cntr++;
    main_flags.tick_1s = 1;
}



//End of ADC conversion (battery voltage)
void ADC1_2_IRQHandler(void)
{
	//JEOC cleared by SW
	ADC1->SR &= ~ADC_SR_JEOC;

	adc_read_bat_voltage_result();
}



uint32_t get_uptime_cntr(void)
{
	return uptime_cntr;
}



uint32_t get_nmea_overflow_cntr(void)
{
	return nmea_overflow_cntr;
}



uint32_t get_lora_tx_cycles_cntr(void)
{
	return lora_tx_cycles_cntr;
}



uint32_t get_lora_rx_cycles_cntr(void)
{
	return lora_rx_cycles_cntr;
}



uint32_t get_abs_pps_cntr(void)
{
	return pps_absolute_cntr;
}



uint32_t get_cont_pps_cntr(void)
{
	return pps_continuous_cntr;
}



uint32_t get_lora_crc_errors_cntr(void)
{
	return lora_crc_err_cntr;
}



uint32_t get_lora_rx_timeouts_cntr(void)
{
	return lora_rx_timeouts_cntr;
}



void setup_interrupt_priorities(void)
{
	#define GROUPS_8_SUBGROUPS_2	(4)

	NVIC_SetPriorityGrouping(GROUPS_8_SUBGROUPS_2);

	NVIC_SetPriority(EXTI2_IRQn, 			NVIC_EncodePriority(GROUPS_8_SUBGROUPS_2, 0, 0));		//GPS PPS Interrupt
	NVIC_SetPriority(TIM1_UP_IRQn, 			NVIC_EncodePriority(GROUPS_8_SUBGROUPS_2, 0, 1));		//Timer1 GPS Acquire + Radio Run

	NVIC_SetPriority(EXTI0_IRQn, 			NVIC_EncodePriority(GROUPS_8_SUBGROUPS_2, 1, 0));		//Radio Interrupt
	NVIC_SetPriority(DMA1_Channel3_IRQn, 	NVIC_EncodePriority(GROUPS_8_SUBGROUPS_2, 1, 1));		//DMA GPS UART RX overflow

	NVIC_SetPriority(DMA1_Channel5_IRQn, 	NVIC_EncodePriority(GROUPS_8_SUBGROUPS_2, 2, 0));		//DMA SPI2 TX LCD
	NVIC_SetPriority(TIM3_IRQn, 			NVIC_EncodePriority(GROUPS_8_SUBGROUPS_2, 2, 1));		//Scan buttons interval

	NVIC_SetPriority(EXTI3_IRQn,			NVIC_EncodePriority(GROUPS_8_SUBGROUPS_2, 3, 0));		//DOWN/ESC button interrupt
	NVIC_SetPriority(EXTI4_IRQn,			NVIC_EncodePriority(GROUPS_8_SUBGROUPS_2, 3, 1));		//UP/OK button interrupt

	NVIC_SetPriority(EXTI9_5_IRQn, 			NVIC_EncodePriority(GROUPS_8_SUBGROUPS_2, 4, 0));		//PWR button interrupt
	NVIC_SetPriority(TIM4_IRQn, 			NVIC_EncodePriority(GROUPS_8_SUBGROUPS_2, 4, 1));		//Compass update interval

	NVIC_SetPriority(RTC_IRQn, 				NVIC_EncodePriority(GROUPS_8_SUBGROUPS_2, 5, 0));		//Uptime counter (every 1 second)
	NVIC_SetPriority(USART1_IRQn, 			NVIC_EncodePriority(GROUPS_8_SUBGROUPS_2, 5, 1));		//Console RX symbol

	NVIC_SetPriority(DMA1_Channel4_IRQn, 	NVIC_EncodePriority(GROUPS_8_SUBGROUPS_2, 6, 0));		//Console UART TX DMA completed
	NVIC_SetPriority(ADC1_2_IRQn, 			NVIC_EncodePriority(GROUPS_8_SUBGROUPS_2, 6, 1));		//End of ADC conversion (battery voltage)

	NVIC_SetPriority(SysTick_IRQn, 			NVIC_EncodePriority(GROUPS_8_SUBGROUPS_2, 7, 0));		//End of beep
	NVIC_SetPriority(EXTI15_10_IRQn, 		NVIC_EncodePriority(GROUPS_8_SUBGROUPS_2, 7, 1));		//ALARM button or ACC interrupt
}

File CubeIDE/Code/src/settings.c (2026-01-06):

/*
    SPOKE

    file: settings.c
*/

#include "stm32f10x.h"
#include "main.h"
#include "settings.h"
#include "memory.h"
#include "gpio.h"
#include "service.h"
#include "lcd.h"
#include "gps.h"
#include "timer.h"
#include "lrns.h"



void settings_interactive_save_default(void);



#define UPDATE_INTERVAL_10S_VALUE		(10)
#define UPDATE_INTERVAL_30S_VALUE		(30)
#define UPDATE_INTERVAL_60S_VALUE		(60)
#define UPDATE_INTERVAL_120S_VALUE		(120)

#define UPDATE_INTERVAL_VALUES_ARRAY 	{ 	UPDATE_INTERVAL_10S_VALUE, 	\
											UPDATE_INTERVAL_30S_VALUE, 	\
											UPDATE_INTERVAL_60S_VALUE,	\
											UPDATE_INTERVAL_120S_VALUE}



#define TX_POWER_NEG9DBM_VALUE   	(-9)
#define TX_POWER_POS0DBM_VALUE   	(0)
#define TX_POWER_POS10DBM_VALUE   	(10)
#define TX_POWER_POS14DBM_VALUE   	(14)
#define TX_POWER_POS22DBM_VALUE  	(22)

#define TX_POWER_VALUES_ARRAY 		{ 	TX_POWER_NEG9DBM_VALUE, 	\
										TX_POWER_POS0DBM_VALUE, 	\
										TX_POWER_POS10DBM_VALUE, 	\
										TX_POWER_POS14DBM_VALUE,	\
										TX_POWER_POS22DBM_VALUE		}



#define BL_LEVEL_OFF_VALUE   		(0x2030)	//" 0"
#define BL_LEVEL_LOW_AUTO_VALUE		(0x6131)	//"a1"
#define BL_LEVEL_MID_AUTO_VALUE		(0x6132)	//"a2"
#define BL_LEVEL_HIGH_AUTO_VALUE	(0x6133)	//"a3"
#define BL_LEVEL_LOW_CONST_VALUE    (0x6331)	//"c1"
#define BL_LEVEL_MID_CONST_VALUE   	(0x6332)	//"c2"
#define BL_LEVEL_HIGH_CONST_VALUE  	(0x6333)	//"c3"

#define BL_LEVEL_VALUES_ARRAY 		{ 	BL_LEVEL_OFF_VALUE, 		\
										BL_LEVEL_LOW_AUTO_VALUE, 	\
										BL_LEVEL_MID_AUTO_VALUE, 	\
										BL_LEVEL_HIGH_AUTO_VALUE,	\
										BL_LEVEL_LOW_CONST_VALUE, 	\
										BL_LEVEL_MID_CONST_VALUE, 	\
										BL_LEVEL_HIGH_CONST_VALUE	}



//positions:
#define SETTINGS_INIT_FLAG_POS          	(0)	//starts form 0
#define SETTINGS_DEVICE_NUMBER_POS      	(1)
#define SETTINGS_DEVICES_ON_AIR_POS			(2)
#define SETTINGS_DEVICE_ID_POS          	(3)
#define SETTINGS_UPDATE_INTERVAL_POS        (4)
#define SETTINGS_FREQ_CHANNEL_POS       	(5)
#define SETTINGS_TX_POWER_POS           	(6)
#define SETTINGS_TIMEOUT_THRESHOLD_POS   	(7)
#define SETTINGS_FENCE_THRESHOLD_POS   		(8)
#define SETTINGS_TIME_ZONE_DIR_POS			(9)
#define SETTINGS_TIME_ZONE_HOUR_POS			(10)
#define SETTINGS_TIME_ZONE_MINUTE_POS		(11)
#define SETTINGS_BL_LEVEL_POS				(12)
#define SETTINGS_MUX_STATE_POS				(13)
#define SETTINGS_MAGN_OFFSET_X_POS			(14)
#define SETTINGS_MAGN_OFFSET_Y_POS			(15)
#define SETTINGS_MAGN_SCALE_X_POS			(16) //2 bytes
#define SETTINGS_MAGN_SCALE_Y_POS			(18) //2 bytes

//default values:
#define SETTINGS_INIT_FLAG_DEFAULT      	(0xAA)
#define SETTINGS_DEVICE_NUMBER_DEFAULT  	(DEVICE_NUMBER_FIRST)
#define SETTINGS_DEVICES_ON_AIR_DEFAULT		(DEVICE_NUMBER_LAST)
#define SETTINGS_DEVICE_ID_DEFAULT 			(DEVICE_ID_FIRST_SYMBOL)
#define SETTINGS_UPDATE_INTERVAL_DEFAULT    (UPDATE_INTERVAL_10S_SETTING)
#define SETTINGS_FREQ_CHANNEL_DEFAULT   	(FREQ_CHANNEL_FIRST)
#define SETTINGS_TX_POWER_DEFAULT       	(TX_POWER_POS10DBM_SETTING)
#define SETTINGS_TIMEOUT_THRESHOLD_DEFAULT  (60)
#define SETTINGS_FENCE_THRESHOLD_DEFAULT  	(100)
#define SETTINGS_TIME_ZONE_DIR_DEFAULT		(1)
#define SETTINGS_TIME_ZONE_HOUR_DEFAULT		(0)
#define SETTINGS_TIME_ZONE_MINUTE_DEFAULT	(0)
#define SETTINGS_BL_LEVEL_DEFAULT			(BL_LEVEL_LOW_AUTO_SETTING)
#define SETTINGS_MUX_STATE_DEFAULT			(MUX_STATE_USB)
#define SETTINGS_MAGN_OFFSET_X_DEFAULT		(0)
#define SETTINGS_MAGN_OFFSET_Y_DEFAULT		(0)
#define SETTINGS_MAGN_SCALE_XM_DEFAULT		(0x3f80)	//float 1.0
#define SETTINGS_MAGN_SCALE_XL_DEFAULT		(0x0000)
#define SETTINGS_MAGN_SCALE_YM_DEFAULT		(0x3f80)	//float 1.0
#define SETTINGS_MAGN_SCALE_YL_DEFAULT		(0x0000)

//settings size
#define SETTINGS_SIZE						(20) //half-words (i.e. bytes)



uint16_t settings_array[SETTINGS_SIZE];
struct settings_struct settings;

uint8_t update_interval_values[] = UPDATE_INTERVAL_VALUES_ARRAY;
int8_t tx_power_values[] = TX_POWER_VALUES_ARRAY;
uint16_t bl_level_values[] = BL_LEVEL_VALUES_ARRAY;

uint8_t pending_interactive_save_defaults = 0; //since settings are loaded before lcd init, the flag is set to accomplish interactive settings reset after lcd init



uint8_t *get_update_interval_values(void)
{
	return &update_interval_values[0];
}



int8_t *get_tx_power_values(void)
{
	return &tx_power_values[0];
}



uint16_t *get_bl_level_values(void)
{
	return &bl_level_values[0];
}



struct settings_struct *get_settings(void)
{
	return &settings;
}
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

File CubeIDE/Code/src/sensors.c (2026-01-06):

/*
    SPOKE

    file: sensors.c
*/



#include "stm32f10x.h"
#include "i2c.h"
#include "sensors.h"
#include "lsm303dlhc.h"



#define ACC_HORIZ_THRS	(900)	//threshold value for Z axis when checking horizontality
#define ACC_KALMAN_K 	(0.15)	//Kalman filter coefficient for accelerometer
#define MAG_KALMAN_K 	(0.4)	//Kalman filter coefficient for magnetometer



struct acc_data acceleration;
struct mag_data magnetic_field;

float acc_k = ACC_KALMAN_K;
float mag_k = MAG_KALMAN_K;


uint8_t acc_first_run = 0;	//flags to indicate first run in order to properly initialize previous sensor value for Kalman filtering
uint8_t mag_first_run = 0;



uint8_t init_accelerometer(void)	//always enabled for movement detection
{
	if (i2c_poll(LSM303_ADDR_ACC))
	{
		i2c_write(LSM303_ADDR_ACC, LSM303_REG_ACC_CTRL_REG2_A, LSM303_ACC_CTRL_REG2_A__HPF);
		i2c_write(LSM303_ADDR_ACC, LSM303_REG_ACC_CTRL_REG3_A, LSM303_ACC_CTRL_REG3_A__I1_AOI1);
		i2c_write(LSM303_ADDR_ACC, LSM303_REG_ACC_CTRL_REG4_A, LSM303_ACC_CTRL_REG4_A__FS2G_HR);
		i2c_write(LSM303_ADDR_ACC, LSM303_REG_ACC_CTRL_REG6_A, LSM303_ACC_CTRL_REG6_A__H_LACTIVE);
		i2c_write(LSM303_ADDR_ACC, LSM303_REG_ACC_INT1_CFG_A, LSM303_ACC_INT1_CFG_A__MOVEMENT_HIGH_XYZ);
		i2c_write(LSM303_ADDR_ACC, LSM303_REG_ACC_INT1_THS_A, LSM303_ACC_INT1_THS_A);
		i2c_write(LSM303_ADDR_ACC, LSM303_REG_ACC_CTRL_REG1_A, LSM303_ACC_CTRL_REG1_A__100ODR_NORM_XYZ);

		return 1;
	}
	else
	{
		return 0;
	}
}



uint8_t init_magnetometer(void)	//enabled only when compass is needed (in navigation and calibration menus)
{
	if (i2c_poll(LSM303_ADDR_MAG))
	{
		i2c_write(LSM303_ADDR_MAG, LSM303_REG_MAG_CRA_REG_M, LSM303_MAG_CRA_REG_M__75HZ);
		i2c_write(LSM303_ADDR_MAG, LSM303_REG_MAG_CRB_REG_M, LSM303_MAG_CRB_REG_M__40GS);
		i2c_write(LSM303_ADDR_MAG, LSM303_REG_MAG_MR_REG_M, LSM303_MAG_MR_REG_M__SLEEP);
		return 1;
	}
	else
	{
		return 0;
	}
}



void start_magnetometer(void)
{
	i2c_write(LSM303_ADDR_MAG, LSM303_REG_MAG_MR_REG_M, LSM303_MAG_MR_REG_M__CONT);
}



void stop_magnetometer(void)
{
	i2c_write(LSM303_ADDR_MAG, LSM303_REG_MAG_MR_REG_M, LSM303_MAG_MR_REG_M__SLEEP);
}



void read_accel(void)
{
	int16_t acc_z_prev;
	uint8_t buf[6];

	acc_z_prev = acceleration.acc_z.as_integer; //save for Kalman filter

	i2c_read_multiple(LSM303_ADDR_ACC, LSM303_REG_ACC_OUT_X_L_A, 6, buf);

	acceleration.acc_x.as_array[0] = buf[0];
	acceleration.acc_x.as_array[1] = buf[1];
	acceleration.acc_y.as_array[0] = buf[2];
	acceleration.acc_y.as_array[1] = buf[3];
	acceleration.acc_z.as_array[0] = buf[4];
	acceleration.acc_z.as_array[1] = buf[5];

	acceleration.acc_x.as_integer /= 16;	//signed shift right 4 bit, align 12 bit data in 16 bit wide type (HR bit must be 1 in CTRL_REG4_A to enable 12 bit result)
	acceleration.acc_y.as_integer /= 16;
	acceleration.acc_z.as_integer /= 16;

	acceleration.acc_y.as_integer *= -1;	//invert Y and Z due to physical location of the sensor on the PCB
	acceleration.acc_z.as_integer *= -1;	//after this correction and for the device in normal orientation: X - to the right, Y - forward, Z - up into face

	//Kalman filtration of Z axis because it is the only used
	if (acc_first_run == 1)
	{
		acc_first_run = 0; //clear after first run; no changes to acc value
	}
	else //not the first run, use prev value
	{
		acceleration.acc_z.as_integer = (int16_t)(acc_k * acceleration.acc_z.as_integer + (1 - acc_k) * acc_z_prev);
	}
}



void read_magn(void)
{
	int16_t mag_x_prev;
	int16_t mag_y_prev;
	uint8_t buf[6];

	mag_x_prev = magnetic_field.mag_x.as_integer;
	mag_y_prev = magnetic_field.mag_y.as_integer;

	i2c_read_multiple(LSM303_ADDR_MAG, LSM303_REG_MAG_OUT_X_H_M, 6, buf);

	magnetic_field.mag_x.as_array[1] = buf[0];
	magnetic_field.mag_x.as_array[0] = buf[1];
	magnetic_field.mag_z.as_array[1] = buf[2];
	magnetic_field.mag_z.as_array[0] = buf[3];
	magnetic_field.mag_y.as_array[1] = buf[4];
	magnetic_field.mag_y.as_array[0] = buf[5];

	magnetic_field.mag_z.as_integer *= -1;	//invert Y and Z due to physical location of the sensor on the PCB
	magnetic_field.mag_y.as_integer *= -1;	//after this correction and for the device in normal orientation: X - to the right, Y - forward, Z - up into face

	//Kalman filtration of X and Y axes because they are only used
	if (mag_first_run == 1)
	{
		mag_first_run = 0; //clear after first run; no changes to mag values
	}
	else //not the first run, use prev value
	{
		magnetic_field.mag_x.as_integer = (int16_t)(mag_k * magnetic_field.mag_x.as_integer + (1 - mag_k) * mag_x_prev);
		magnetic_field.mag_y.as_integer = (int16_t)(mag_k * magnetic_field.mag_y.as_integer + (1 - mag_k) * mag_y_prev);
	}
}



uint8_t is_horizontal(void)
{
	read_accel();
	if (acceleration.acc_z.as_integer > ACC_HORIZ_THRS)
	{
		return 1;
	}
	else
	{
		return 0;
	}
}



void sensors_mark_as_first_run(void)
{
	acc_first_run = 1;
	mag_first_run = 1;
}



struct acc_data *get_acceleration(void)
{
	return &acceleration;
}



struct mag_data *get_magnetic_field(void)
{
	return &magnetic_field;
}

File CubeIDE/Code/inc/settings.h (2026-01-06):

/*
    SPOKE

    file: settings.h
*/



#ifndef SETTINGS_HEADER
#define SETTINGS_HEADER

#include "config.h"



#define TIMEOUT_ALARM_DISABLED		(0)
#define FENCE_ALARM_DISABLED		(0)



//Update interval settings
#define UPDATE_INTERVAL_10S_SETTING		(0)
#define UPDATE_INTERVAL_30S_SETTING		(1)
#define UPDATE_INTERVAL_60S_SETTING		(2)
#define UPDATE_INTERVAL_120S_SETTING	(3)

#define UPDATE_INTERVAL_FIRST_OPTION 	(UPDATE_INTERVAL_10S_SETTING)
#define UPDATE_INTERVAL_LAST_OPTION 	(UPDATE_INTERVAL_120S_SETTING)


//POWER SETTINGS
#define TX_POWER_NEG9DBM_SETTING   	(0)
#define TX_POWER_POS0DBM_SETTING    (1)
#define TX_POWER_POS10DBM_SETTING   (2)
#define TX_POWER_POS14DBM_SETTING   (3)
#define TX_POWER_POS22DBM_SETTING  	(4)

#define TX_POWER_FIRST_OPTION 		(TX_POWER_NEG9DBM_SETTING)
#define TX_POWER_LAST_OPTION 		(TX_POWER_POS22DBM_SETTING)



//LCD BL Levels
#define BL_LEVEL_OFF_SETTING   			(0)
#define BL_LEVEL_LOW_AUTO_SETTING		(1)
#define BL_LEVEL_MID_AUTO_SETTING		(2)
#define BL_LEVEL_HIGH_AUTO_SETTING		(3)
#define BL_LEVEL_LOW_CONSTANT_SETTING   (4)
#define BL_LEVEL_MID_CONSTANT_SETTING   (5)
#define BL_LEVEL_HIGH_CONSTANT_SETTING  (6)

#define BL_LEVEL_FIRST_OPTION 		(BL_LEVEL_OFF_SETTING)
#define BL_LEVEL_LAST_OPTION 		(BL_LEVEL_HIGH_CONSTANT_SETTING)



//FREQ
#ifdef FREQ_BAND_433
#define FREQ_CHANNEL_FIRST  (1)
#define FREQ_CHANNEL_LAST   (8)	//see radio.c
#endif

#ifdef FREQ_BAND_868
#define FREQ_CHANNEL_FIRST  (1)
#define FREQ_CHANNEL_LAST   (21)	//see radio.c
#endif


//ID
#define DEVICE_ID_FIRST_SYMBOL      ('A')
#define DEVICE_ID_LAST_SYMBOL       ('Z')



//TIMEOUT
#define TIMEOUT_THRESHOLD_MIN 	(0)
#define TIMEOUT_THRESHOLD_MAX 	(3600)
#define TIMEOUT_THRESHOLD_STEP 	(10)



//FENCE
#define FENCE_THRESHOLD_MIN 	(0)
#define FENCE_THRESHOLD_MAX 	(5000)
#define FENCE_THRESHOLD_STEP 	(10)



//MUX
#define MUX_STATE_USB_SYMBOL	('U')
#define MUX_STATE_BLE_SYMBOL	('B')



//Structure with settings
struct settings_struct
{
    uint8_t device_number;              //this device number in group, 1...DEVICES_IN_GROUP

    uint8_t devices_on_air;				//total number of devices on air, 1...DEVICES_IN_GROUP

    char device_id;      				//user id, ASCII symbol

    uint8_t freq_channel;               //frequency tx/rx channel, LPD #1-69

    uint8_t tx_power_opt;               //tx power option, not an actual value

    uint8_t update_interval_opt;		//update interval option, not an actual value

    uint16_t timeout_threshold;        	//timeout treshold in seconds, unsigned. if it == 0, then timeout alarm not trigger (but, anyway, timeout is counting). See TIMEOUT_ALARM_DISABLED

    uint16_t fence_threshold;        	//fence treshold in meters, unsigned. if it == 0, then fence alarm not trigger. See FENCE_ALARM_DISABLED

    int8_t time_zone_dir;				//can be -1 or 1

    int8_t time_zone_hour;				//can be 0 ... 14 if time_zone_dir = 1; and 0 ... 12 if time_zone_dir = -1

    int8_t time_zone_minute;			//can be 0, 15, 30, 45

    uint8_t bl_level_opt;				//LCD backlight level option, not an actual value

    uint8_t mux_state_opt;				//Console MUX state, also corresponds to the MUX pin state

    int16_t magn_offset_x;				//magnetometer offset X for hard iron compensation

    int16_t magn_offset_y;				//magnetometer offset Y for hard iron compensation

	union
	{
		float as_float;         		//magnetometer scale X for soft iron compensation
		uint16_t as_array[2];
	} magn_scale_x;

	union
	{
		float as_float;         		//magnetometer scale Y for soft iron compensation
		uint16_t as_array[2];
	} magn_scale_y;
};



struct settings_struct *get_settings(void);
uint8_t *get_update_interval_values(void);
int8_t *get_tx_power_values(void);
uint16_t *get_bl_level_values(void);
void process_pending_save_default(void);
void settings_save_default(void);
void settings_load(void);
void settings_save(struct settings_struct *settings);



#endif /*SETTINGS_HEADER*/

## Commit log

2023-02-26 Upload the design to git
    [Spoke.kicad_pcb, Spoke.kicad_sch]
2023-02-26 Roughly update silkscreen designators
    [Spoke.kicad_pcb]
2023-03-05 Update reference designators text size
    [Spoke.kicad_pcb]
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2023-03-05 Place stitching vias - bottom part
    [Spoke.kicad_pcb]
2023-03-05 Place stitching vias - top part
    [Spoke.kicad_pcb]
2023-03-05 Resolve DRC errors, update dates
    [Spoke.kicad_pcb, Spoke.kicad_sch]
2023-03-12 Replace LCD BL and LCD MISO nets with CONSOLE RX/TX nets
    Update PCB with changes
    [Spoke.kicad_pcb, Spoke.kicad_sch]
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2023-03-26 Make changes to SCH
    -Add x3 header for CLI
    -Add UART TX protection resistor
    -Add I2C test points
    -Re-annotate
    [Spoke.kicad_sch]
2023-03-26 Import and apply changes to PCB
    [Spoke.kicad_pcb, Spoke.kicad_sch]
2023-03-26 Update PCB silkscreen, change dates
    [Spoke.kicad_pcb, Spoke.kicad_sch]
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2023-04-16 Add buzzer beep function
    [main.c, timer.c, timer.h]
2023-04-18 Fix for LEDs and UART echo
    [gpio.c, uart.c]
2023-04-19 Attempt to fix buzzer beep
    [gpio.c, lcd.c, main.c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]
2023-04-19 Fix buttons interrupt trigger edge
    [gpio.c]
2023-04-19 Fix buttons order
2023-04-19 Disable JTAG and fix IRQ for the power button
    [gpio.c]
2023-04-20 Fix GPS RX pin mode
    [gpio.c]
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2023-05-11 Add sx1268 workaround "15.2"
    [radio.c]
2023-05-18 Complex fix
    -change irq status to 16 bit
    -restore LPD CH1 frequency
    -set preamble length to 3 bytes
    -enable RX timeout again and set it to 50 ms
    -process rx_timeout interrupt
    [main.c, radio.c, radio.h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]
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2023-05-23 Add Enterprise enclosure files
    [Enterprise_bottom.stl, Enterprise_top.stl]
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2023-06-01 Accelerometer fix for multiple bytes reading
    [i2c.c]
2023-06-01 Magnetometer fix for continuous mode
    [sensors.c]
2023-06-01 Fix accelerometer data alignment
    [sensors.c]
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2023-06-10 Invert accel and magn Y and Z axises according to the sensor location on PCB
    [main.c, sensors.c]
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2023-06-10 Add calibration restart option, fix Y axis direction
    [lcd.c]
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2023-06-18 Change buttons scan logic
    in order to prevent wrong buttons scan operation when CPU is processing compass update
    [main.c]
2023-06-22 Fix North calculatin math, now the device acts like a pointer, not a compass
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2023-06-23 Fix dma stop conditions
    [lcd.c, main.c]
2023-06-23 Fix mem & per addresses, set data transfer direction
    [spi.c]
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2023-06-25 Add busy flag wait in spi2_trx() to fix the lcd glitch
    [spi.c]
2023-07-12 i2c multiple read fix attempt #1
    [i2c.c, main.c]
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2023-07-26 Fix bug with LCD goes corrupted when locking the device
    [lcd.c]
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2023-08-23 Update LEDs logic
    -Blink green on RF TX or RF RX
    -Blink red on any error (synchronous with beep)
    [main.c, timer.c]
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2023-09-03 Add reset to default at power up
    [settings.c]
2023-09-03 Fix save default which occurs after re-flash
    [main.c, settings.c]
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2023-11-01 Fix ubx buffer size
    [gps.c, uart.c]
2023-11-01 Fix wrong uart port, isolate timepulse and confirm it has been applied correctly
    [gps.c]
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2023-11-03 Fix calculation error in battery icon
    [adc.c]
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2023-11-05 Add interactive menu for 'settings reset to default' routine
    [settings.c]
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2023-11-10 WIP gps reset to default routines
    [gps.c, main.c]
2023-11-10 Fix GPS RX frame error bug, add GPS restore to default to settings restore func
    [gpio.c, gps.c, main.c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]
2023-11-11 Fix LCD blink glitch by checking is it busy to prevent lcd buffer corruption
    [lcd.c, main.c]
2023-11-11 Fix low power mode for GPS
    [gps.c]
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2023-11-21 Fix jump to bootloader
    [service.c]
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2024-01-07 Config radio for LoRa modulation; add workarounds
    [main.c, radio.c, radio.h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]
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2024-01-07 Fix timeout; successful TX/RX
    [radio.c, sx126x.h]
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2024-01-15 Fix scope for check alarm/fence/timeout
    [gps.c, lcd.c]
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2024-01-28 Fix TEMP pin connection of the U5; Increase revision to 1.1
    [Spoke.kicad_pcb, Spoke.kicad_sch]
2024-01-28 Fix silk revision; export gerbers
    [Spoke-B_Cu.gbl, Spoke-B_Mask.gbs, Spoke-B_Silkscreen.gbo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]
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2024-04-21 Fix compass arrow freeze after going from horizontal orientation
    [main.c]
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2024-05-08 Fix all_flags rewrite bug
    [uart.c]
2024-05-25 Add Voyager enclosure files
    [Voyager_bottom.stl, Voyager_top.stl]
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2024-06-02 Move GPS module 2 mm down, to be aligned with buttons center
    [Spoke.kicad_pcb]
2024-06-02 Update GPS footprint, add text captions to lines
    [Spoke.kicad_pcb, Spoke.kicad_sch]
2024-06-02 Update stack-up to 1.58 mm
    [Spoke.kicad_pcb]
2024-06-02 Update stack up again so the overall thickness is 1.6mm
    [Spoke.kicad_pcb]
2024-06-02 Plot Gerbers, update readme
    [Spoke-B_Cu.gbl, Spoke-B_Mask.gbs, Spoke-B_Silkscreen.gbo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]
2024-06-02 Remove old, upload and rename new files
    [Enterprise_bottom.stl, Enterprise_top.stl, Spoke_Enterprise_Bot_1.0mm.stl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]
2024-06-02 Upload Pioneer 1.6mm files
    [Spoke_Pioneer_Bot_1.6mm.stl, Spoke_Pioneer_Cap_1.6mm.stl, Spoke_Pioneer_Top_1.6mm.stl]
2024-06-02 Upload Pioneer 1.0mm files
    [Spoke_Pioneer_Bot_1.0mm.stl, Spoke_Pioneer_Cap_1.0mm.stl, Spoke_Pioneer_Top_1.0mm.stl]
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2024-09-15 Fix and improve beep clear feature
    [main.c]
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2024-09-15 Fix delay_cyc() affected by optimization
    [service.c]
2024-09-22 Fix power lock upon bootloader start
    [service.c]
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2024-10-05 Update captions in settings reset menu
    [settings.c]
2024-10-05 Reset to defaults when ESC is pressed upon powering up
    [settings.c]
2024-10-20 Prevent complete power off after reset caused by watchdog
    [service.c]
2024-10-20 Add watchdog reset before WFI
    [main.c, timer.c, timer.h]
2024-10-21 Add iwdt reload for settings reset; update settings reset caption
    [settings.c]
2024-10-21 Replace table-defined calendar by calculated one
    [gps.c, service.c]
2024-10-21 Fix array indexing in calendar
    [gps.c]
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2024-10-27 Fix initial timeout alarm for our device if there are no other active devs
    [main.c]
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2024-10-28 Fix restart after reset bug
    [service.c, settings.c]
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2024-11-03 Improve power hold after software reset
    [service.c]
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2024-11-11 Fix i2c stop wait
    [i2c.c]
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2024-11-11 Comment out GPS reset to default
    GPS is no longer configured, nor reset to default; so no lock to a specific GPS receiver
    [settings.c]
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2024-11-21 Fix power hold after settings reset to default
    [settings.c]
2024-11-23 Remove previous output content
    [Spoke-B_Cu.gbl, Spoke-B_Mask.gbs, Spoke-B_Silkscreen.gbo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]
2024-11-23 Export files to PROD folder
    [Spoke-B_Cu_Rev_1.2.gbl, Spoke-B_Mask_Rev_1.2.gbs, Spoke-B_Paste_Rev_1.2.gbp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]
2024-11-23 Edit .gitignore to show up csv BOM
    [Spoke_Rev_1.2.csv]
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2024-12-16 Fix lcd plot limiting; switch magn to 4 G range
    [lcd.c, sensors.c]
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2025-01-01 Fix RSSI value typecast
    [radio.c]
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2025-03-02 Change critical and low battery level thresholds
    Fix Battery icon leveling, fix boundary bug
    [adc.c]
2025-03-16 Update GPS/UART
    -Replace 4800 by 38400
    -Extend GPS UART buffer; allocate buf size dynamically depending on baud speed
    -calc_timeout() calculated each second independently
    [gps.c, main.c, settings.c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]
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2025-04-12 Convert project files to a new KiCad version
    [Spoke.kicad_pcb, Spoke.kicad_sch]
2025-04-12 Replace LDO by DCDC
    [Spoke.kicad_sch]
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2025-04-16 Replace L1212 by L1616 footprint
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2025-04-18 Draw boot button circuit
    [Spoke.kicad_sch]
2025-04-19 Add BLE UART module
    [Spoke.kicad_sch]
2025-04-19 Draw UART connection matrix
    [Spoke.kicad_sch]
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2025-04-19 Place SCH todo notes
    [Spoke.kicad_sch]
2025-04-21 Add multiplexer instead of uart interonnection matrix
    [Spoke.kicad_sch]
2025-04-24 Add MUX_BLE_USB control line; add LCD backlight circuit
    [Spoke.kicad_sch]
2025-04-26 Fix multiple items
    [Spoke.kicad_sch]
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2025-04-26 Replace 8M crystal
    [Spoke.kicad_sch]
2025-04-26 Add 6x6 SMD button
    [Spoke.kicad_sch]
2025-04-27 Replace LCD
    [Spoke.kicad_sch]
2025-04-27 Rough Import to PCB
    [Spoke.kicad_pcb, Spoke.kicad_sch]
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2025-05-05 Lots of changes to SCH symbols, designators, library components
    [Spoke.kicad_sch]
2025-05-10 Fixes and glossing
    [Spoke.kicad_sch]
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2025-05-15 SCH finished, annotate all
    [Spoke.kicad_sch]
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2025-05-16 Fix overlay text size in footprints
    [Spoke.kicad_pcb]
2025-05-16 Import SCH to PCB
    [Spoke.kicad_pcb]
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2025-05-17 Simplify UART lines, add USB UART conn
    [Spoke.kicad_sch]
2025-05-17 Add MHs and import to PCB
    [Spoke.kicad_pcb, Spoke.kicad_sch]
2025-05-17 Remove unused switches, arrangement
    [Spoke.kicad_pcb, Spoke.kicad_sch]
2025-05-18 Power part components arrangement
    [Spoke.kicad_pcb]
2025-05-18 Arrange the rest components
    [Spoke.kicad_pcb]
2025-05-21 Move e-compass to the top
    [Spoke.kicad_pcb]
2025-05-30 Replace LEDs by 3 mm
    [Spoke.kicad_pcb, Spoke.kicad_sch]
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2025-06-08 Fix in place WIP
    [Spoke.kicad_pcb]
2025-06-08 Replace DCDC caps by Ceramic 10 uF
    [Spoke.kicad_pcb, Spoke.kicad_sch]
2025-06-08 Fix in place except MCU
    [Spoke.kicad_pcb]
2025-06-08 Fix MCU
    [Spoke.kicad_pcb]
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2025-09-07 Routing mainly done; VCC left
    [Spoke.kicad_pcb]
2025-09-13 Update SCH with notes, add R23
    [Spoke.kicad_pcb, Spoke.kicad_sch]
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2025-09-13 Update design rules per JLCPCB
    [Spoke.kicad_pcb]
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2025-09-13 DRC fix #1
    [Spoke.kicad_pcb]
2025-09-13 DRC fix #2
    [Spoke.kicad_pcb]
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2025-09-13 GND vias along edges
    [Spoke.kicad_pcb]
2025-09-13 PCB done, Silk todo
    [Spoke.kicad_pcb]
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2025-09-19 Swap pins J1
    [Spoke.kicad_pcb, Spoke.kicad_sch]
2025-09-19 Add Q1 reverse polarity protection
    [Spoke.kicad_pcb, Spoke.kicad_sch]
2025-09-20 Remove rev 1.2 output
    [Spoke-B_Cu_Rev_1.2.gbl, Spoke-B_Mask_Rev_1.2.gbs, Spoke-B_Paste_Rev_1.2.gbp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]
2025-09-20 Set rev 2 date
    [Spoke.kicad_pcb, Spoke.kicad_sch]
2025-09-20 Export SCH and BOM
    [Spoke.kicad_sch, Spoke_BOM_Rev_2.0.csv]
2025-09-20 Update PCB from SCH
    [Spoke.kicad_pcb]
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2025-09-21 Export gerber and drills
    [Spoke.kicad_pcb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]
2025-09-21 Update BOM with description
    [Spoke_BOM_Rev_2.0.csv]
2025-11-26 Add POWER_HOLD fix config
    [gpio.c]
2025-11-29 Implement buzzer single-ended PWM
    [main.c, timer.c, timer.h]
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2025-11-29 Independent buzzer and backlight operation
    but timer is always on
    [timer.c]
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2025-11-30 Fix error and add pending save default processing
    [main.c, settings.c, settings.h]
2025-12-03 Fix Cancel action in save default menu
    [settings.c]
2025-12-04 Fix bl on when lcd gets off
    [lcd.c]
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2025-12-15 Add endeavour enclosure stl files
    [button.stl, pin.stl, stvorka.stl]
2025-12-16 Move files to folder
    [button.stl, pin.stl, stvorka.stl]
2025-12-17 Fix i2c clock enable delay
    [i2c.c]
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2025-12-17 Bring BL freq low, closer to Buzzerr freq to reduce screen flickering, while making it quiet when BL is lit
    [timer.c]
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2025-12-19 Add UART RX errors handling
    [main.c]
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2026-01-07 Swap PWR_HOLD and RF_TXEN; re-route
    [Spoke.kicad_pcb, Spoke.kicad_sch]
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2026-01-07 Move LCD_BL to PA1 (ex BUZZER_N)
    [Spoke.kicad_pcb, Spoke.kicad_sch]
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2026-01-07 Tentatively move LEDs and ALARM button
    [Spoke.kicad_pcb]
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2026-01-08 Set Alarm button position
    [Spoke.kicad_pcb]
2026-01-08 Replace R31 to 1 kOhm
    [Spoke.kicad_pcb, Spoke.kicad_sch]
2026-01-08 Draw buzzer drive circuit
    [Spoke.kicad_sch]
2026-01-08 Route buzzer circuit
    [Spoke.kicad_pcb, Spoke.kicad_sch]
2026-01-10 Wire GPS to MUX
    [Spoke.kicad_pcb, Spoke.kicad_sch]
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2026-01-10 Implement latest in routing
    [Spoke.kicad_pcb]
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2026-01-10 Update SCH symbols from lib
    [Spoke.kicad_sch]
2026-01-10 Increase pin1 silk marks
    [Spoke.kicad_pcb]
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2026-01-10 Mainly route new GPS
    [Spoke.kicad_pcb, Spoke.kicad_sch]
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2026-01-12 Add text blocks with notes
    [Spoke.kicad_sch]
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2026-01-14 Small fixes
    [Spoke.kicad_pcb]
2026-01-17 Review schematic and up rev to 2.1
    [Spoke.kicad_sch]
2026-01-17 Sync PCB with SCH and up PCB rev to 2.1
    [Spoke.kicad_pcb]
2026-01-17 Move LEDs and Alarm btn 1.5 mm to the right
    [Spoke.kicad_pcb, Spoke.kicad_sch]
2026-01-17 Review PCB for errors
    [Spoke.kicad_pcb]
2026-01-17 Switch back to GPS on wires populated
    [Spoke.kicad_pcb, Spoke.kicad_sch]
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
